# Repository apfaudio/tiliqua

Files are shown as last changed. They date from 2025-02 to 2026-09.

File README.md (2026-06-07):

# Tiliqua

**Tiliqua is a powerful, open hardware FPGA-based audio multitool for Eurorack.** It looks like this:



# ⮕[Documentation](https://apfaudio.github.io/tiliqua/)⬅

# Updates / Community

For updates, subscribe to the [Crowd Supply page](https://www.crowdsupply.com/apfaudio/tiliqua), join the [matrix chatroom](https://matrix.to/#/#apfaudio:matrix.org), or my own [mailing list](https://apf.audio/).

`apfaudio` has a Matrix channel, [#apfaudio:matrix.org](https://matrix.to/#/#apfaudio:matrix.org). Feel free to join to ask questions or discuss ongoing development.

Participants in this project are expected to adhere to the [Berlin Code of Conduct](https://berlincodeofconduct.org/).

# Contributing

For contribution guidelines and our policy on AI/LLM usage, see [CONTRIBUTING.md](CONTRIBUTING.md).

# Acknowledgements

This project would be nothing without the hard work of many (awesome) open-source projects. An exhaustive list would take pages, here I mention only a crucial subset:

- Python-based HDL and SoC framework: The [Amaranth HDL](https://github.com/amaranth-lang/amaranth) and [Amaranth SoC](https://github.com/amaranth-lang/amaranth-soc) projects.
- USB and SoC gateware: The [LUNA and Cynthion](https://github.com/greatscottgadgets/luna/) projects.
- RISCV softcore: The [VexRiscv and SpinalHDL projects](https://github.com/SpinalHDL/VexRiscv)
- USB audio gateware and descriptors: The [adat-usb2-audio-interface](https://github.com/hansfbaier/adat-usb2-audio-interface) project.
- Some gateware (e.g. I2C state machines) are inherited from the [Glasgow](https://github.com/GlasgowEmbedded/glasgow) project.
- Audio interface and gateware: my existing [eurorack-pmod](https://github.com/apfaudio/eurorack-pmod) project.
- SID emulation gateware: [reDIP-SID](https://github.com/daglem/reDIP-SID)
- The "mi-plaits-dsp-rs" project: [mi-plaits-dsp](https://github.com/sourcebox/mi-plaits-dsp-rs)
- The "pico-dirtyJtag" project forms a big chunk of the RP2040 firmware [pico-dirtyJtag](https://github.com/phdussud/pico-dirtyJtag)

## Funding

We would like to acknowledge partial funding of the [Tiliqua project](https://nlnet.nl/project/Tiliqua/) from the [NGI Commons Fund](https://nlnet.nl/commonsfund), a fund established by [NLnet](https://nlnet.nl/) with financial support from the European Commission’s [Next Generation Internet](https://ngi.eu/) program.



# License

The hardware and gateware in this project is largely covered under the CERN Open-Hardware License V2 CERN-OHL-S, mirrored in the LICENSE text in this repository. Some gateware and software is covered under the BSD 3-clause license - check the header of the individual source files for specifics.

**Copyright (C) 2024 Sebastian Holzapfel**

The above LICENSE and copyright notice do NOT apply to imported artifacts in this repository (i.e datasheets, third-party footprints), or dependencies released under a different (but compatible) open-source license.

# Derivative works

As an addendum to the above license: if you create or manufacture your own derivative hardware, the name `apf.audio`, the names of any `apf.audio` products and the names of the authors, are *not to be used in derivative hardware or marketing materials*, except where obligated for attribution and for retaining the above copyright notice.

For example, your 3U adaptation of "apf.audio Tiliqua" could be called "Gizzard Modular - Lizardbobulator".

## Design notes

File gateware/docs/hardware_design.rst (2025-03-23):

Electrical Design
#################

Tiliqua consists of 3 PCBAs. All of these are open-hardware designs built in KiCAD and stored in separate repositories.

Block Diagram (Tiliqua R4)
--------------------------

Below is high-level picture of how all the different electrical components of Tiliqua are connected.



Some connections are omitted for simplicity (example: some ex0/ex1 pins are connected to both the ECP5 and RP2040, not shown).

Pinouts and schematics
----------------------
- **Pinout information is available in 'amaranth-boards'** `format here <https://github.com/apfaudio/tiliqua/blob/main/gateware/src/tiliqua/tiliqua_platform.py>`_.
- **Schematics for all PCBAs in the wild are plotted** `to PDFs here <https://github.com/apfaudio/tiliqua/tree/main/hardware/schematics>`_.

We now follow with a summary of the core functions of each of the Tiliqua PCBAs.

Tiliqua Motherboard
-------------------

**Repository:** `tiliqua-motherboard <https://github.com/apfaudio/tiliqua/tree/main/hardware>`_

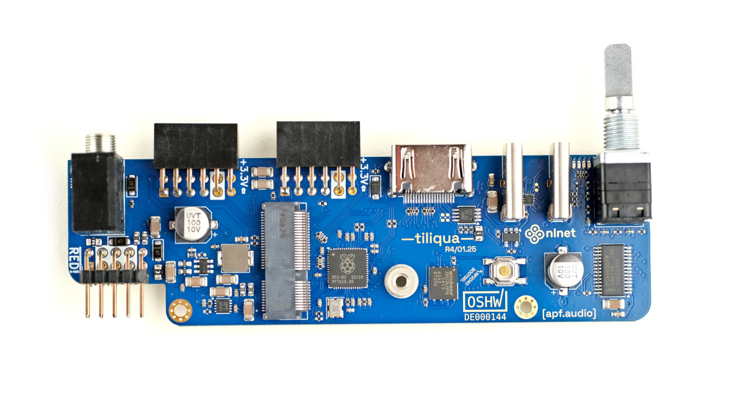
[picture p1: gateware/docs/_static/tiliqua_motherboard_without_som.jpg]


- Rotary encoder with button and bar graph display.
- RP2040-based JTAG debugger and UART bridge supported by `openFPGAloader`.
- Two USB ports:
    - `dbg`: USB FS for JTAG debugging.
    - `usb2`: 480Mbit/sec USB HS PHY connected to FPGA. Device, host and dual-role operation is supported on this port with a dedicated TUSB322I CC control IC and +5V VBUS switch.
- Display output for video synthesis
    - Maximum resolution 1280x720p/60Hz or 1920x1080p/30Hz.
- 2x (PMOD-compatible) expansion ports for up to 24 simultaneous audio channels.
- MIDI-In jack (TRS-A standard) with optoisolation.
- External PLL (SI5351A) for dynamic display resolution switching.
- Soft mute for pop-free bitstream switching

FPGA SoM (`soldiercrab`)
------------------------

**Repository:** `soldiercrab <https://github.com/apfaudio/soldiercrab>`_ (see README there for more detailed docs on this SoM)

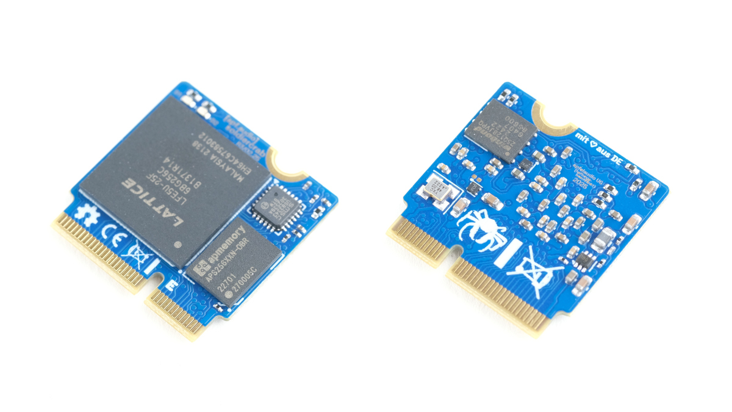
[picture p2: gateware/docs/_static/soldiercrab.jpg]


- Lattice ECP5 (25 K) FPGA, supported by open-source FPGA toolchains
- 256 Mbit (32 MByte) HyperRAM / oSPI RAM (for long audio buffers or video framebuffers)
- 128 Mbit (16 MByte) SPI flash for user bitstreams
- High-speed USB HS PHY (ULPI)

Audio Interface (`eurorack-pmod R3.3`)
--------------------------------------

**Repository:** `eurorack-pmod <https://github.com/apfaudio/eurorack-pmod/tree/master/hardware>`_

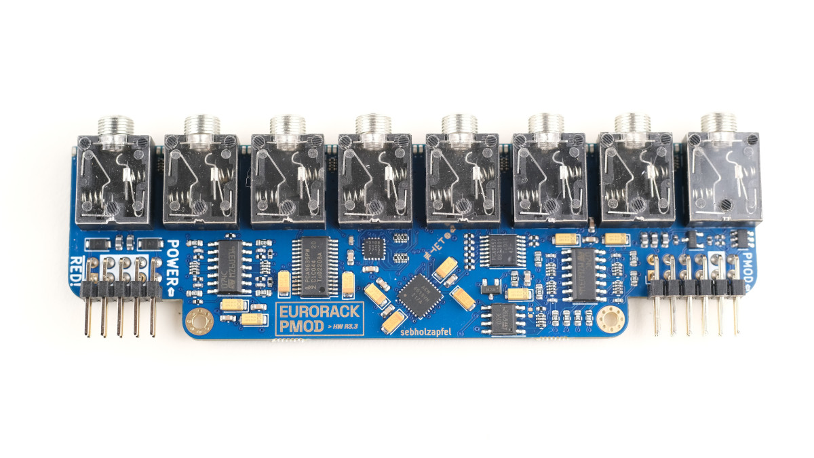
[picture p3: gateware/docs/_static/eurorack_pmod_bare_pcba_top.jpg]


- 8 (4 in + 4 out) DC-coupled audio channels, 192 KHz / 24-bit sampling
- Touch and proximity sensing on all 8 audio jacks (if unused)
- PWM-controlled, user-programmable red/green LEDs on each audio channel
- Jack insertion detection on all 8 jacks
- Built-in calibration EEPROM

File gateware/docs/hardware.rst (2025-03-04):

Connecting Hardware
###################

Connections: Front
------------------



Connections: Back
-----------------



Power: connecting +/- 12V
-------------------------

.. warning::

    Tiliqua uses an ordinary 10-pin power cable for +/- 12V ingress. You will notice however, that there are 2 such connectors on the module. **Only ONE of these should be connected**:

    - Use the 10-pin power ingress **on the Tiliqua Motherboard, not the Audio Interface Board**. Technically both will work, but only the former is fused.
    - Both connectors on the audio interface board (eurorack-pmod) should remain unconnected.
    - Make sure the red stripe on the IDC cable is aligned with the RED marker on the PCB.

USB: the ``dbg`` and ``usb2`` ports
-----------------------------------

For flashing bitstreams, you want the ``dbg`` USB port. This is routed to the on-board RP2040 which is flashed with ``dirtyJtag``, which allows flashing the SPI flash with ``openFPGALoader``.

For USB audio or USB device / host usage from bitstreams, you want the ``usb2`` USB port. This is routed through a ULPI PHY directly to the FPGA fabric.

Audio jacks: for touch, disconnect on boot
------------------------------------------

When using bitstreams with touch sensing, **ensure all jacks are disconnected before the tiliqua is powered on**. This is because the capacitive sensing is calibrated when the system boots. In the future, re-calibration will happen every time something is dis/re-connected, but this is not the case yet.

Display/DVI: disconnect when system off
---------------------------------------

External displays (e.g. external monitors not sharing Eurorack power) may leak a small current to the FPGA through the DVI termination resistors if Tiliqua is off. This will not affect Tiliqua operation, but may affect the 3V3 supply on PMOD expansion modules. By always **disconnecting the display when your eurorack system is off**, you can avoid this leakage current.

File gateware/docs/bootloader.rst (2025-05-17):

Bootloader
##########

User Interface
--------------

The bootloader allows you to arbitrarily select from one of 8 bitstreams after the Tiliqua powers on, without needing to connect a computer. In short:

- When Tiliqua boots, you can select a bitstream with the encoder (either using the display output, or by reading the currently lit LED if no display is connected).
- When you select a bitstream (press encoder), the bootloader bitstream:
    - Loads any required firmware to PSRAM and sets up any other settings requested in the bitstream manifest.
    - Commands the RP2040 over UART to issue a bitstream reconfiguration.
    - The RP2040 then commands the ECP5 (over JTAG) to reconfigure itself and enter the selected bitstream (loaded from the SPI flash local to the ECP5).
- From any bitstream, you can always go back to the bootloader by holding the encoder for 3sec (this is built into the logic of every bitstream).

Bitstream Archives and Flash Memory Layout
------------------------------------------

Tiliqua user projects are packaged into *Bitstream Archives*, which are ``.tar.gz`` files that contain everything the bootloader needs to start a custom bitstream. Each bitstream archive contains:

- Bitstream file (top.bit)
- Firmware binary (if applicable)
- Any extra resources to be loaded into PSRAM (if applicable)
- Manifest file (human-readable ``.json``) describing the contents

Tiliqua's ``pdm flash`` command manages the memory layout on the SoldierCrab's SPI flash, ensuring that the components of a bitstream archive end up in the correct place. A picture of how the SPI flash is organized:

.. code-block:: text

    ┌────────────────────────────┐  0x000000
    │                            │
    │    Bootloader Bitstream    │
    │                            │
    ├────────────────────────────┤
    │          (padding)         │
    ├────────────────────────────┤  0x0B0000
    │                            │
    │    Bootloader FW (XiP)     │
    │                            │
    ├────────────────────────────┤
    │          (padding)         │
    ╞════════════════════════════╡  0x100000
    │                            │
    │      Slot 0 Bitstream      │
    │                            │
    ├────────────────────────────┤
    │          (padding)         │
    ├────────────────────────────┤  0x1B0000
    │                            │
    │        Slot 0 FW           │
    │  NOT XiP, copied to PSRAM  │
    │                            │
    ├────────────────────────────┤  (any additional slot 0 resources appended here)
    │          (padding)         │
    ├────────────────────────────┤  0x1FFC00
    │      Slot 0 Manifest       │
    ╞════════════════════════════╡  0x200000 (End of Slot 0, start of Slot 1)
    │                            │
    │      Slot 1 Bitstream      │
    │                            │
    ├────────────────────────────┤
    │          (padding)         │
    ├────────────────────────────┤  0x2B0000
    │                            │
    │        Slot 1 FW           │
    │  NOT XiP, copied to PSRAM  │
    │                            │
    ├────────────────────────────┤ (any additional slot 1 resources appended here)
    │          (padding)         │
    ├────────────────────────────┤  0x2FFC00
    │       Slot 1 Manifest      │
    ╞════════════════════════════╡  0x300000 (End of Slot 1, start of Slot 2)
    │                            │

    ... continued up to Slot 7

- Bootloader bitstream: 0x000000
- User bitstream slots: 0x100000, 0x200000, etc (1MB spacing)
- Manifest: End of each slot (slot 0: 0x100000 + 0x100000 - 1024 (manifest size))
- Firmware: Loaded into PSRAM by bootloader, usually fixed offset from the bitstream start (i.e firmware for slot 0 is loaded from 0x100000 + 0xB0000 = 0x1B0000)

The manifest includes metadata like the bitstream name and version, as well as information about where firmware should be loaded in PSRAM.

If an image requires firmware loaded to PSRAM, the SPI flash source address (in the manifest) is set to the true firmware base address by the flash tool when it is flashed.
That is, the value of ``spiflash_src`` is not preserved by the flash tool and instead depends on the slot number.
This allows a bitstream that requires firmware to be loaded to PSRAM to be flashed to any slot, and the bootloader will load the firmware from the correct address.

Flashing the RP2040 and bootloader bitstream
--------------------------------------------

During normal use, it should not be necessary to flash the RP2040 or bootloader bitstream. However the instructions here may be useful for unbricking a device if you accidentally erased the bootloader, or want to update the bootloader on older hardware revisions. The bootloader is composed of 2 components that work together:

- The RP2040 firmware (`apfbug - fork of dirtyJTAG <https://github.com/apfaudio/apfbug>`_)
- The `bootloader <https://github.com/apfaudio/tiliqua/tree/main/gateware/src/top/bootloader>`_ top-level bitstream.

Flashing Steps
^^^^^^^^^^^^^^

1. Flash the RP2040. Use the latest pre-built binaries `found here <https://github.com/apfaudio/apfbug/releases>`_. To flash them, hold RP2040 BOOTSEL (golden button on the Tiliqua motherboard) before applying power, then copy the :code:`build/*.uf2` to the usb storage device and power cycle Tiliqua again. If you don't want to remove Tiliqua from your rack, you can also enter the RP2040 bootloader by opening a serial port at 1200 baud.

2. Build and flash the bootloader bitstream using the built-in flash tool (alternatively just download the latest bootloader archive from the CI artifacts):

.. code-block:: bash

    # Flash bootloader to start of flash, build assuming XIP (execute directly from SPI flash, not PSRAM)
    # Be careful to replace `--hw r4` with your hardware revision!
    pdm bootloader build --hw r4 --fw-location=spiflash
    pdm flash archive build/bootloader-r4/bootloader-*.tar.gz

3. Build and flash any other bitstreams you want to slots 0..7 (you can also download these archives from CI artifacts):

.. code-block:: bash

   # assuming the archive has already been built / downloaded
   pdm flash archive build/xbeam-r4/xbeam-*.tar.gz --slot 2

2. Check what is currently flashed in each slot (by reading out the flash manifests):

.. code-block:: bash

   pdm flash status

3. Before using the new bitstreams, disconnect the USB port and power cycle Tiliqua. (note: for the latest RP2040 firmware, this is not necessary and you can use them straight away).

.. warning::

    Before ``apfbug`` beta2 firmware, the bootloader would NOT reboot correctly (just show a blank screen) if you have
    the :py:`dbg` USB port connected WITHOUT a tty open. You HAD to have the
    ``/dev/ttyACM0`` open OR have the ``dbg`` USB port disconnected for it to work correctly.
    `Tracking issue (linked) <https://github.com/apfaudio/apfbug/issues/2>`_ (resolved in beta2 FW).

4. Now when Tiliqua boots you will enter the bootloader. Use the encoder to select an image. Hold the encoder for >3sec in any image to go back to the bootloader.

Technical Details
-----------------

Bootloader bitstream: ECP5
^^^^^^^^^^^^^^^^^^^^^^^^^^

The ECP5 :code:`bootloader` bitstream copies firmware from SPI flash to PSRAM before jumping to user bitstreams by asking the RP2040 to execute a stub bitstream replay (load a special bitstream to SRAM that jumps to the new bitstream). The request is issued over UART from the ECP5 to the RP2040, so it is visible if you have the ``/dev/ttyACMX`` open. User bitstreams are responsible for asserting PROGRAMN when the encoder is held to reconfigure back to the bootloader.

`apfbug` debugger firmware: RP2040
^^^^^^^^^^^^^^^^^^^^^^^^^^^^^^^^^^

:code:`apfbug` firmware includes the same features as :code:`pico-dirtyjtag` (USB-JTAG and USB-UART bridge), with some additions:

- UART traffic is inspected to look for keywords.
- If a keyword is encountered e.g. :code:`BITSTREAM1`, a pre-recorded JTAG stream stored on the RP2040's SPI flash is decompressed and replayed. The JTAG streams are instances of the `bootstub <https://github.com/apfaudio/tiliqua/blob/main/gateware/src/top/bootstub/top.py>`_ top-level bitstream. These are tiny bitstreams that are programmed directly into SRAM with the target :code:`bootaddr` and PROGRAMN assertion.
- This facilitates ECP5 multiboot (jumping to arbitrary bitstreams) without needing to write to the ECP5's SPI flash and exhausting write cycles.

Recording new JTAG streams for RP2040
^^^^^^^^^^^^^^^^^^^^^^^^^^^^^^^^^^^^^

TODO documentation on recording new JTAG bitstreams for storage on RP2040 flash - not necessary to change this for ordinary Tiliqua usecases. Note: SoldierCrab R3 and R2 use different ECP5 variants, so they need different RP2040 images. This is addressed by the ``TILIQUA_HW_VERSION_MAJOR`` cmake flag in the ``apfbug`` project.

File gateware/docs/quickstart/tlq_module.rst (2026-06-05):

Tiliqua Module [``TLQ-MODULE``]
###############################

**Tiliqua is shipped with a bunch of example bitstreams already flashed to it. So, to get started, all you need to do is connect the Eurorack +/- 12V ribbon cable, connect a screen, and then switch the Eurorack power on.**

.. warning::

    I recommend **only plugging or unplugging the display, power, or expansion headers while your system is OFF**. All other TRS jacks / USB connectors are fine to hotplug!



Connecting Power
^^^^^^^^^^^^^^^^

To power Tiliqua, you only need to connect the 16-pin Eurorack power input (+/- 12V) which, out of the box, is already attached to Tiliqua in the correct orientation.

.. note::

    Tiliqua comes with a rainbow power cable rather than a boring gray one. The connector is keyed correctly and the BROWN wire is the -12V wire. RED is still closest to -12V like on a standard gray one. Nothing bad will happen if you accidentally connect it backwards (on the 10-pin side), as Tiliqua has input diodes and fuses.

Connecting a Display
^^^^^^^^^^^^^^^^^^^^

Any standard monitor or projector (or our ``TLQ-SCREEN`` module) should work fine as a display for Tiliqua. In general, Tiliqua tries to use the native resolution of any attached screen. However, if the native resolution is higher than ``1280x720p60``, or no screen is connected at all, we always emit a display signal at ``1280x720p60`` as a fallback - as the vast majority of screens support this resolution.

Bootloader
^^^^^^^^^^

After powering on your system, you will be greeted by the bootloader screen:



From here, you can use the encoder to select one of 8 slots. As each slot is highlighted, the I/O mapping of each jack and plug is pictured on the right. You will notice some bitstreams have USB, some don't, some have a display output and others don't (like the audio-only bitstreams).

To reboot into a selected bitstream, just press the encoder button. **Once you're in a bitstream, you can always hold the encoder button down for 3sec (long press) to mute Tiliqua and re-enter the bootloader.**

.. note::

   At the moment, the screen resolution and/or any screen hotplugs are only detected in the bootloader. This is not a hardware limitation, but it does mean that for now you always need to be in the bootloader to change screen resolutions. The current resolution is displayed at the bottom of the bootloader screen.

   In general, bitstreams will show ``video: <match-bootloader>`` if they are able to inherit the resolution automatically detected by the bootloader. If a bitstream only supports a static mode, you will see something like ``video: 1280x720p60``. If a bitstream does not have any video output, you will see ``video: <none>``.

Menu / Help system
^^^^^^^^^^^^^^^^^^

In theory, each user bitstream could have a completely different UI. For now though, most bitstreams that have a display output and are shipped with Tiliqua follow the same menu UI. That is:

    - Each bitstream has multiple 'pages', where the first page is a 'HELP' page.
    - Rotating the encoder allows you to select a different menu option or the current page name.
    - If the current page name is selected, pressing the encoder will toggle between modifying the current page or not, rotating it will switch to a different page.
    - If normal option is selected, pressing the encoder will toggle between modifying the value or not, rotating it will increase or decrease the value.
    - In this way, you can access one of many pages and modify one of many options on each page with the single encoder.
    - If no option is selected for modification and we are not on the help page, the UI will disappear after some time (useful for generating visualizations).



    HELP page for XBEAM user bitstream.

Using Bitstreams
^^^^^^^^^^^^^^^^

.. note::

    The instructions here are always for the **latest firmware** - if the version shown at the bottom of the screen for any bitstream is not up-to-date (matching the latest `version number / changelist here <https://github.com/apfaudio/tiliqua/releases>`_), I recommend updating! (instructions below)

Out of the box, Tiliqua ships with the following example bitstreams flashed. Many of them have built-in help pages. Here is a link to some more info on each one:

- :ref:`XBEAM <xbeam>`
- :ref:`POLYSYN <polysyn>`
- :ref:`MACRO-OSC <macro_osc>`
- :ref:`SID <sid>`
- :doc:`SELFTEST <../calibration>`
- :ref:`SAMPLER <sampler>`
- :class:`DSP-MDIFF <top.dsp.top.PSRAMMultiDiffuser>`
- `VSYNTH <https://github.com/apfaudio/tiliqua/issues/160>`_ (preview!)

.. warning::

    The documentation for each bitstream is not quite polished yet, but I hope there is enough material for you to be able to get started with the most important ones.

Jack LEDs
^^^^^^^^^

Normally, the Jack LEDs on each audio jack show the current voltage on the jack. However, whenever you are modifying an option or touching the encoder, the jack LEDs take on a different meaning.

This is because, in cases where you want to use a bitstream that has a menu system but **don't have space for a display** (and are extremely dedicated and memorised the menu) it is possible to navigate purely based on the jack LEDs!

    - If jack LED is green: we are selecting a page. The jack LED number (0-7) is the page number.
    - If jack LED is red: we are selecting an option. The jack LED number (0-7) is the option index.
    - If the jack LED is flashing: we are in 'modify' mode. If it is not flashing, we are NOT in 'modify' mode.
    - The bar graph LEDs around the encoder show the currently selected option's value on a scale from min (fully green) to max (fully red).

Touch Sensors
^^^^^^^^^^^^^

The capacitive touch sensors on each jack are calibrated when Tiliqua is turned on, and in some bitstreams (like POLYSYN), automatically re-calibrated every time a jack is plugged or unplugged. If you are having issues with 'ghost' touches, it's often worth power cycling tiliqua with nothing patched on the jacks you want to use for touch sensing.

USB: the ``dbg`` and ``usb2`` ports
-----------------------------------

For flashing bitstreams, you want the ``dbg`` USB port. This is routed to the on-board RP2040. For USB audio or USB device / host usage from bitstreams, you want the ``usb2`` USB port. This is routed through a ULPI PHY directly to the FPGA fabric.

.. note::

   **If you are having trouble with the ``usb2`` port for USB audio streaming or as a MIDI host**, I have collected some :doc:`USB troubleshooting tips here <../usb_troubleshooting>`.

Flashing/Updating Bitstreams
^^^^^^^^^^^^^^^^^^^^^^^^^^^^

Tiliqua can be updated / flashed in 2 ways:

- Use the **tiliqua-webflash** `(LINK) <https://apfaudio.github.io/tiliqua-webflash/>`_ tool, which works in any Chromium-based browser and allows you to flash bitstream archives to Tiliqua using any OS.
- Using our ``pdm flash`` **command line tool**, which requires setting up the Tiliqua development environment first. More details in :doc:`../install`.

With **tiliqua-webflash**, the latest release is always shown - no need to download anything. For command line, you can find the latest `published release here <https://github.com/apfaudio/tiliqua/releases>`_.

Tiliqua has 9 slots (bootloader + 8 user slots). Generally, you want to keep all of these up-to-date, however, as they are independent, you can have different versions of things in every slot. You'll find instructions on how to update each slot in the respective flashing tool.

.. note::

    **Technical details for the curious!** Tiliqua has 3 persistent memory chips that come pre-flashed out of the box. **Flashing / updating bitstreams only touches the first one.**

        - On the 'Soldiercrab': one 16MB SPI flash for the FPGA: This one contains the bootloader bitstream and all the user bitstreams, and any saved options.
        - On the 'Motherboard':  16MB SPI flash for the RP2040 / debugger: this one contains the debugger firmware used as a bridge between the ``dbg`` USB port and the FPGA JTAG.
        - On the 'Audio Board': one small EEPROM for storing calibration constants, as well as the last entered bitstream used for autoboot. This contains the factory calibration.

    **Under the hood**: updating or changing the bootloader bitstream or user bitstreams is performed using an open-source tool called ``openFPGALoader``, as Tiliqua shows up as a ``dirtyJtag``-compatible debug adapter. Bitstreams for Tiliqua are distributed as *Bitstream Archives*, which contain firmware and metadata alongside the bitstream itself. For technical details on how this works, see :doc:`../bootloader`).

Calibration
^^^^^^^^^^^

Tiliqua is shipped with a factory calibration to within 5mV or so. If you want to get even better, you can try to calibrate it yourself by following the calibration sequence here: :doc:`../calibration`

.. warning::

    Before you conclude the NCO V/oct calibration is bad, note the calibration currently is only applied in bitstreams that have a menu system as reading the calibration uses a CPU. This limitation will be removed in a future update.

Hardware Block Diagram
^^^^^^^^^^^^^^^^^^^^^^

For deeper details (and schematics) of the hardware, see :doc:`../hardware_design`



Instructions for Safe Use
^^^^^^^^^^^^^^^^^^^^^^^^^

- The product shall only be used in a Eurorack system, providing a standard Eurorack power supply not exceeding +/- 12V, and at least 500mA. Any external case, power supply, cables, or modules shall comply with relevant regulations and standards applicable in the country of intended use.
- To reach electromagnetic compatibility in a Eurorack system, the product shall be mounted securely in a fully enclosed housing made of conductive material (metal). Close all unused spaces with blind panels. Keep all cables, power or patch cables as short as possible.
- The product should only be operated in a well ventilated case and should not be covered, except by the Eurorack case itself or other module panels. The product is designed for reliable operation at normal ambient room temperature. Do not expose the module to water, moisture or bring the circuit boards in contact with any conductive materials.
- Take care whilst handling to avoid mechanical or electrical damage. When the product is powered on, do not touch any of the circuit boards behind the front panel. When the product is outside a case, only handle it unpowered and by the edges to minimize the risk of damage from electrostatic discharge.
- Do not supply power to the product through any receptacle except the main +/- 12V power input. Any external devices not sharing the product’s main power bus (e.g. USB host devices or externally powered displays) should be disconnected when the product is unpowered. The incorrect usage or connection of unapproved devices to any receptacle may affect compliance or result in damage to the unit and invalidate the warranty.
- Use of any firmware, gateware or clock frequencies not explicitly provided by the manufacturer is to be done at your own risk, in a controlled laboratory environment, with respect to relevant regulations and standards applicable in the country of intended use.

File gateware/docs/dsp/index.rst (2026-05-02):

DSP Library
###########

Philosophy
----------

Tiliqua's DSP library is designed as a suite of DSP components - independent 'cores' which can be connected together in different ways in order to build a custom DSP pipeline. It makes heavy use of Amaranth streams (`lib.stream <https://amaranth-lang.org/docs/amaranth/latest/stdlib/stream.html>`_) for connecting components and `lib.fixed <https://github.com/amaranth-lang/amaranth/pull/1578>`_ for fixed-point types. `lib.stream <https://amaranth-lang.org/docs/amaranth/latest/stdlib/stream.html>`_ makes it possible to chain DSP components together in different ways (without components needing to know implementation details of each other), and `lib.fixed <https://github.com/amaranth-lang/amaranth/pull/1578>`_ makes it easier to write common numeric operations in Amaranth.

.. note::

    Streams are an Amaranth construct describing a *stream of data* that is accompanied by a ``valid``/``ready`` handshake. This is a simple protocol used commonly in digital logic. For more details, see `Data streams <https://amaranth-lang.org/docs/amaranth/latest/stdlib/stream.html>`_ in the Amaranth documentation.

Interconnect
------------

Building a custom DSP pipeline with the components provided here is often an act of figuring out how to massage the input and output ports of each component such that the design does what you want. In simple cases, like oscillators or filters, DSP components will often have a ``self.i`` stream for incoming and ``self.o`` stream for outgoing samples - these can be chained together in any order using `wiring.connect() <https://amaranth-lang.org/docs/amaranth/latest/stdlib/wiring.html>`_. In more complex cases, like delay lines, components may expose a memory bus (for writes to external memory), multiple input or output ports, or global registers. It is important to read the documentation of each component and take a look at some of the example cores in order to understand how each component can be used, and how exactly input and output samples are synchronized.

As of now, input and output ports of DSP components generally take on one of the following shapes:

    - ``stream.Signature(fixed.SQ)``: A stream of audio samples, one at a time.
    - ``stream.Signature(ArrayLayout(N, fixed.SQ))``: A stream of N audio samples, one 1D array at a time. This is used for multi-channel, time-synchronized inputs and outputs -- like Tiliqua's 4 inputs or 4 outputs, or the :class:`tiliqua.dsp.MatrixMix` component. These can be split into streams of single samples using :class:`tiliqua.dsp.Split` or :class:`tiliqua.dsp.Merge` (see :doc:`stream_util`).
    - ``stream.Signature(StructLayout({...}))``: A stream of N different types of data, one set at a time. This is often used when each audio sample needs a piece of metadata alongside it (e.g. realtime tweakable filters like :class:`tiliqua.dsp.SVF`).
    - ``stream.Signature(Block(...))``: Some components can only operate on blocks of samples, like :class:`tiliqua.dsp.fft.FFT` - see :doc:`block` for details.

The art is in knowing exactly which components can be used in translating between the interface styles. For example, :class:`tiliqua.dsp.fft.ComputeOverlappingBlocks` can help going from a sample stream to a block stream. :class:`tiliqua.dsp.Split` for going from an `ArrayLayout <https://amaranth-lang.org/docs/amaranth/latest/stdlib/data.html#amaranth.lib.data.ArrayLayout>`_ to independent sample streams. Depending on the application, often `StructLayout <https://amaranth-lang.org/docs/amaranth/latest/stdlib/data.html#amaranth.lib.data.StructLayout>`_ streams will need some manual handshaking logic. There is no one right answer for every adaptation, especially in cases where you have some control signals alongside synchronized audio streams.

A few components have auxiliary interfaces to the outside world. Examples are :class:`tiliqua.dsp.DelayLine`, which may have a ``bus`` port to talk to external memory (for storing audio samples), or ``usb_audio`` components which require a connection to a USB PHY to service their audio in/out streams.

'Basic' and 'Specialized' components
------------------------------------

DSP cores are split into 2 types, 'Basic' and 'Specialized'. Basic cores do not require qualified access - after a statement like ``from tiliqua import dsp``, these can be accessed through :class:`dsp.Split <tiliqua.dsp.Split>` or similar. 'Specialized' cores need qualified access and may be accessed through :class:`dsp.fft.STFTProcessor <tiliqua.dsp.fft.STFTProcessor>` or similar.

Basic DSP Components
--------------------

.. toctree::
   :maxdepth: 2

   delay_lines
   filters
   oscillators
   effects
   vca
   mix
   resample
   oneshot
   stream_util
   misc

Specialized Modules
-------------------

.. toctree::
   :maxdepth: 2

   delay_effect
   fft
   spectral
   mac
   block
   complex
   cordic

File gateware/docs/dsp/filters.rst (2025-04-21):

Filters
-------

.. autoclass:: tiliqua.dsp.SVF
.. autoclass:: tiliqua.dsp.FIR
.. autoclass:: tiliqua.delay.Boxcar

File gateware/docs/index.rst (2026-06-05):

Tiliqua Project
###############

The **Tiliqua Project** aims to make FPGA-based audio and video synthesis more accessible.



    TLQ-MODULE and (optional) matching TLQ-SCREEN patched in a Eurorack System

Tiliqua is a **Eurorack Module**, which contains a debugger, FPGA and high-fidelity DC-coupled audio IOs, amongst lots of other features. It can store multiple bitstreams, and has a bootloader to select between them - making the hardware fully reconfigurable during live performance.

.. note::

    **If you just received Tiliqua hardware -- Quickstart is where you should begin!**

.. toctree::
   :caption: Quickstart
   :maxdepth: 2

   quickstart/tlq_module.rst
   quickstart/tlq_screen.rst
   quickstart/tlq_expander.rst
   quickstart/tlq_soldiercrab.rst

.. toctree::
   :caption: Development Guide
   :maxdepth: 3

   install
   building_flashing
   audio_bitstreams
   custom_dsp
   beamrace_video
   cpu_bitstreams
   bootloader

.. toctree::
   :caption: Reference
   :maxdepth: 3

   examples/index
   dsp/index
   calibration
   usb_troubleshooting

.. toctree::
   :caption: Hardware Details
   :maxdepth: 2

   hardware_design
   hardware_changes

.. toctree::
   :caption: Keep Updated
   :maxdepth: 2

   community
   foss_funding
   devlog/index

.. toctree::
   :caption: Links
   :maxdepth: 2

   Tiliqua Webflasher <https://apfaudio.github.io/tiliqua-webflash/>
   Tiliqua on Crowd Supply <https://www.crowdsupply.com/apfaudio/tiliqua>
   Tiliqua on GitHub <https://github.com/apfaudio/tiliqua>
   Homepage (apf.audio) <https://apf.audio/>

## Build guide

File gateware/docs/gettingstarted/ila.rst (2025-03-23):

Using the ILA
=============

Some cores support using a built-in ILA (integrated logic analyzer), to collect waveform traces on the hardware into on-FPGA block RAM, which is sampled at the system clock and dumped out the serial port.

For example:

.. code-block:: bash

   # from `gateware` directory
   pdm vectorscope_no_soc build --ila --ila-port /dev/ttyACM0

This will build the bitstream containing the ILA, flash the bitstream, then open the provided serial port waiting for an ILA dump from the Tiliqua to arrive. Once received, the dump will be saved to a waveform trace file.

.. note::
   You may have to play with permissions for flashing to work correctly - make sure ``openFPGALoader`` can run locally under your user without ``sudo``.

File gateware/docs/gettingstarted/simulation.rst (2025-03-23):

Simulating designs
==================

Simulating DSP cores
--------------------

The easiest way to debug the internals of a DSP project is to simulate it. This project provides some shortcuts to enable simulating designs end-to-end with Verilator (at some point these will be migrated to Amaranths CXXRTL simulation backend, once it lands).

For example, to simulate the waveshaping oscillator example:

.. code-block:: bash

   # from `gateware` directory
   pdm dsp sim --dsp-core nco

In short this command:

- Elaborates your Amaranth HDL and convert it to Verilog
- Verilates your verilog into a C++ implementation, compiling it against ``sim_dsp_core.cpp`` provided in ``gateware/top/dsp`` that excites the audio inputs (you can modify this).
- Runs the verilated binary itself and spits out a trace you can view with ``gtkwave`` to see exactly what every net in the whole design is doing.

Simulating SoC cores
--------------------

A subset of SoC-based top-level projects also support end-to-end simulation (i.e including firmware co-simulation). For example, for the selftest SoC:

.. code-block:: bash

   # from `gateware` directory
   pdm selftest sim

   # ...

   run verilated binary 'build/obj_dir/Vtiliqua_soc'...
   sync domain is: 60000 KHz (16 ns/cycle)
   pixel clock is: 74250 KHz (13 ns/cycle)
   [INFO] Hello from Tiliqua selftest!
   [INFO] PSRAM memtest (this will be slow if video is also active)...
   [INFO] write speed 1687 KByte/seout frame00.bmp
   c
   [INFO] read speed 1885 KByte/sec
   [INFO] PASS: PSRAM memtest

UART traffic from the firmware is printed to the terminal, and each video frame is emitted as a bitmap. This kind of simulation is useful for debugging the integration of top-level SoC components.

Simulating vectorscope core
---------------------------

There is a top-level ``vectorscope_no_soc`` provided which is also useful for debugging integration issues between the video and memory controller cores. This can be simulated end-to-end as follows (``--trace-fst`` is also useful for saving waveform traces):

.. code-block:: bash

   # from `gateware` directory
   pdm vectorscope_no_soc sim --trace-fst

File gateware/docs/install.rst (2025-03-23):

Prerequisites
#############

On an Ubuntu system, the following are the main dependencies:

- The build system: install `pdm <https://github.com/pdm-project/pdm>`_
- For synthesis/simulation: install `oss-cad-suite <https://github.com/YosysHQ/oss-cad-suite-build>`_ (and see note below)
- For any SoC examples that include a CPU: `rust <https://rustup.rs/>`_

  - To build stripped images for RISC-V, you also need:

    .. code-block:: bash

       rustup target add riscv32im-unknown-none-elf
       rustup target add riscv32imafc-unknown-none-elf # for `macro_osc` only, it uses an FPU
       rustup component add rustfmt clippy llvm-tools
       cargo install cargo-binutils svd2rust form

.. note::
    By default, synthesis will use :code:`yowasp-yosys` and :code:`yowasp-nextpnr-ecp5` (python packages), rather than any :code:`oss-cad-suite` you have installed. When running locally, builds are usually faster if you point to your own installation - modify :code:`gateware/.env.toolchain` (simply deleting it will try to find yosys in your PATH).

To set up the repository:

.. code-block:: bash

   cd gateware
   git submodule update --init --recursive

To install all python dependencies in a PDM-managed venv:

.. code-block:: bash

   pdm install

.. note::

    Most examples are built in CI. If you're having trouble setting up your environment, it may also be worth checking the github workflow configuration.

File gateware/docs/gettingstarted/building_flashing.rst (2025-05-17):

Building and flashing examples
==============================

Building
--------

Each top-level bitstream has a command-line interface. You can see the options by running (for example):

.. code-block:: bash

   # from `gateware` directory
   pdm dsp

The available options change depending on the top-level project. For example, many projects have video output, and from the CLI you can select the video modeline.

.. warning::

    For prototype Tiliqua hardware, be careful to add an :py:`--hw r4` (or similar) flag specifying your hardware version to all commands below.

A few examples of building top-level bitstreams:

.. code-block:: bash

   # from `gateware` directory

   # for the selftest bitstream (prints diagnostics out DVI and serial)
   pdm selftest build
   # for a vectorscope / oscilloscope
   pdm xbeam build
   # for a polyphonic MIDI synth
   pdm polysyn build
   # for the LUNA-based 4in + 4out USB soundcard example
   # note: LUNA USB port presents itself on the second USB port (not dbg)!
   pdm usb_audio build
   # for a 4-channel waveshaping oscillator
   pdm dsp build --dsp-core nco
   # for a diffusion delay effect
   pdm dsp build --dsp-core diffuser
   # simplified vectorscope (no SoC / menu system)
   pdm vectorscope_no_soc build

Generally, bitstreams are also built in CI - check ``.github/workflows`` if you need more gruesome details on how systems are built.

For SoC projects that have firmware, for quicker iteration, ``--fw-only`` is useful to only re-build the firmware for that bitstream and repackage the archive, without re-synthesizing the bitstream (which often takes quite a while).

Flashing
--------

When you build projects from the command line, it will create a *Bitstream Archive*, which is a ``.tar.gz`` file that contains everything the bootloader needs to start a custom bitstream. Details on the inner workings of these archives can be found in the :doc:`../bootloader` section.

You can flash custom bitstreams to one of 8 slots, using the built-in ``pdm flash`` command. To flash a bitstream archive you have just built, you can use ``pdm flash archive`` as follows:

.. warning::

    For prototype hardware, you may need to reflash the RP2040 and bootloader bitstream  per :doc:`../bootloader`, before the following instructions will work.

.. code-block:: bash

   # Flash user bitstreams to the desired slot (0-7)
   pdm flash archive build/selftest-r4/selftest-*.tar.gz --slot 1
   pdm flash archive build/xbeam-r4/xbeam-*.tar.gz --slot 2

``pdm flash`` also supplies a ``status`` command to read back the Tiliqua's SPI flash to see what is currently on there:

.. code-block:: bash

   pdm flash status

.. note::

    If you want to avoid audio pops while flashing, it is best to flash from the bootloader bitstream, as the audio CODEC is always muted in that bitstream.

If you are running an SoC, you can monitor serial output like so:

.. code-block:: bash

   sudo picocom -b 115200 /dev/ttyACM0

For non-SoC projects that don't require extra firmware, note that you can also directly flash bitstreams to the SRAM of the FPGA like so:

.. code-block:: bash

   sudo openFPGALoader -c dirtyJtag build/dsp-mirror-r4/top.bit

This flashes much quicker, as we don't have to wait for flash pages to update. This can be useful for quickly iterating on DSP gateware. In the future, this will be possible with SoC bitstreams as well, but requires an extra bridge to directly stream debug firmware to the PSRAM from the host, which isn't implemented yet.

Video Modes
-----------

From the Tiliqua bootloader (or whenever a display is hotplugged whilst in the bootloader), Tiliqua reads the attached display EDID to determine which display timings to use. Tiliqua will adapt to the first timing descriptor it finds, and if none of them can be met (usually if the pixel clock is too fast), it falls back to 1280x720p60. You can inspect the logs as to how the bootloader decided which display mode to use by looking at the serial telemetry on the debug port.

Depending on the project, Tiliqua user bitstreams may:

- Not use the video output at all (for example ``pdm dsp`` and ``pdm usb_audio`` are audio-only)
- Use a static video mode (for example ``pdm vectorscope_no_soc``)
- Support dynamic video modes (all SoC bitstreams)

Dynamic video modes are useful as the same bitstream can be used/shared, regardless of which screen is plugged in. When dynamic video modes are supported, the user bitstream will inherit the video mode that was autodetected by the bootloader (this is communicated by a ``bootinfo`` struct saved to PSRAM before the user bitstream is booted).

.. note::

   If for some reason you want to disable EDID reading and use a static/specific mode, you can always re-build and re-flash all bitstreams using a flag like ``--modeline 1280x720p60`` to force a static modeline, disabling dynamic mode detection. Note that the bootloader built with a static modeline can *only* start bitstreams that are also built with a static modeline, however a bootloader built for dynamic modelines can start *both* types of bitstreams. The bootloader will display an error if these conditions are not met.

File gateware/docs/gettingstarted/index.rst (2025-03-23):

Getting Started
###############

.. toctree::
   building_flashing
   simulation
   ila

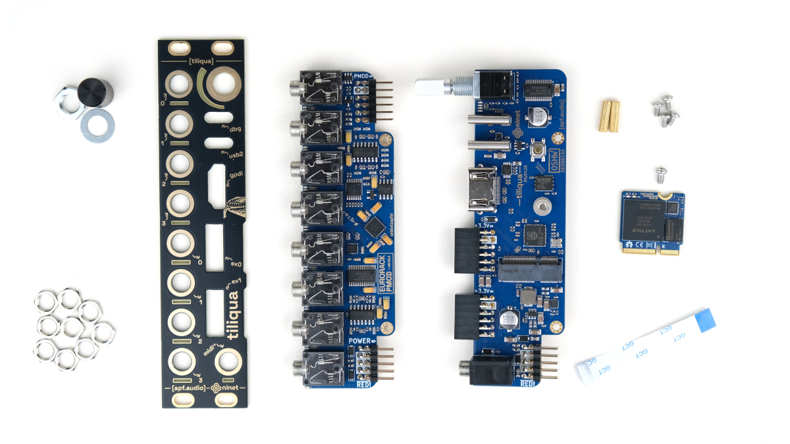
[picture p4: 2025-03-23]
gateware/docs/_static/tiliqua_disassembled_top.jpg

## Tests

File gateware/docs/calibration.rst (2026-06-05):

Calibration
###########

Background
----------

To support eurorack-level control voltages (CV), all inputs and outputs are DC-coupled. Audio codecs (such as the AK4619VN used here) are usually not designed for DC-coupled operation, which means that they often have quite large DC zero offsets and scaling terms compared to instrumentation converters.

.. note::

    Without any calibration at all, the inputs and outputs will should have an error < 150mV or so across the range. Most examples will deal with this fine, however if you are driving or being driven by Eurorack V/oct tunings, 1 semitone is in the order 80mV. So, if you need to be pitch-perfect, calibration is worthwhile.

To reduce the tracking error, each input and output supports independent DC offset and scale correction factors:

- For input ADCs, ``i = A * I + B``, where ``i`` is the calibrated input, ``I`` is the raw ADC count and ``A``, ``B`` are correction factors.
- For output DACs, ``O = C * o + D``, where ``o`` is the desired output, ``C`` and ``D`` are correction factors, and ``O`` is the raw DAC count.

Note that internally, the correction algorithm for inputs and outputs is identical. At the moment, audio samples are 16-bit fixed-point (shorthand ``ASQ`` in the code) with a range from ``-1..1`` where (when calibrated) ``+1 == +8.192V`` (i.e 4 raw counts per mV). Both input and output sides can support wider voltage ranges, however this is currently what the codebase uses everywhere, and wide enough for most purposes.

All correction factors are stored as 18-bit fixed-point numbers with a range ``-4..4``. Usually the scaling correction factors are close to ``1``, and the zeroing correction factors are close to ``0``.

Calibrating the ADCs/DACs
-------------------------

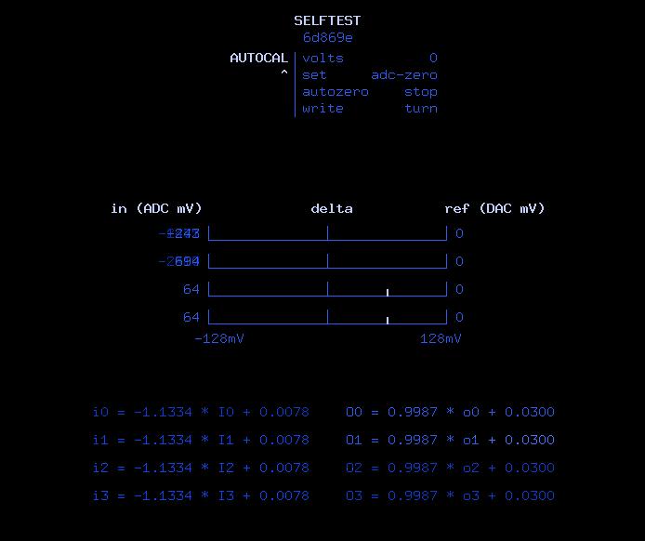
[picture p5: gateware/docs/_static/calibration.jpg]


Pictured above, the ``selftest`` bitstream provides a semi-automated way of performing ADC/DAC calibration.
In short, the process is as follows:

- Disconnect all jacks. Power up Tiliqua, select ``selftest`` bitstream, ensure startup report is healthy.
- Switch to the ``AUTOCAL`` screen. The display will show the following options:

    - ``volts``: DAC reference level. This determines the value sent to the DAC. It is also subtracted from the ADC readings to form the 'delta' plot pictured on the main screen.
    - ``set``: Calibration coefficient to be automatically adjusted. The utility will adjust the selected coefficients until the 'delta' plot on the main screen has been zeroed.
    - ``autozero``: Enable autozero. When set to ``off``, nothing is adjusted. When set to ``run``, the selected calibration coefficients will be adjusted. Usually, you switch to ``run`` until the values are zeroed, then switch it off again.
    - ``write``: Write constants to non-volatile EEPROM and print them out the serial port.

- **Step 1** ADC zero:

  - With all jacks disconnected, set ``volts=0``, ``set=adc-zero``.
  - Switch ``autozero=run`` until the 'delta' plots hit zero. Switch back to ``autozero=stop``
  - You will notice the calibration equations at the bottom of the screen updated during the zeroing process.

- **Step 2** ADC scale:

  - Set an external precise voltage source to the desired test voltage, for example 3V.
  - With the first jack connected to your voltage source, set ``volts=3``, ``set=adc-scale``.
  - Switch ``autozero=run`` until the 'delta' plots hit zero.
  - Plug in the voltage source to the other jacks in sequence until they all also hit zero. Alternatively, you can just plug all the jacks into one voltage source at the same time, that's up to you.
  - Switch back to ``autozero=stop``
  - Now the ADCs are calibrated, you can test the range by injecting different voltages and adjusting ``volts`` to move the reference.

- **Step 3** DAC zero:

  - Now that all the ADCs are calibrated, we can use the ADC calibration to calibrate the DACs.
  - Connect all outputs to inputs in loopback with 4 patch cables (i.e. output 0 to input 0, output 1 to input 1 and so on).
  - Set ``volts=0``, ``set=dac-zero``. You will see see the DAC output zero offsets, as the ADCs were already zeroed.
  - Switch ``autozero=run`` until the 'delta' plots hit zero. Switch back to ``autozero=stop``

- **Step 4** DAC scale:

  - Set ``volts=3``, ``set=dac-scale``. The ADC readings should already be pretty close to the target.
  - Switch ``autozero=run`` until the 'delta' plots hit zero. Switch back to ``autozero=stop``

- **Step 5** Save the results

  - Select ``write`` from the menu and turn the encoder to save the calibration to non-volatile EEPROM on the eurorack-pmod PCBA. The constants are also printed out the serial port. On switching to other bitstreams or returning to this bitstream, the previous calibration will be loaded from EEPROM.

.. note::

    As of now, the calibration constants are only loaded from EEPROM in bitstreams that have an SoC. If you want to use the calibration constants in a bitstream without a SoC, for now you can copy and paste the serial-port dump into the default calibration you will find in ``eurorack_pmod.py``.

- **You are done!** optionally, you can also tweak the cal constants from the ``TWEAK-ADC`` and ``TWEAK-DAC`` screens.

.. note::

    **On R4 (and earlier) Tiliqua hardware:** During calibration, you may notice the DC offsets moving around ~10mV depending on whether the LEDs are on or off. This is due to the CODEC voltage regulator. In any case, it's best to do the calibration assuming the LEDs are ON, as that is the state they will be in most of the time Tiliqua is being used.

    **On R5+ Tiliqua hardware:** Reproducible calibration at <5mV absolute accuracy should be easy to achieve, since I added an extra voltage regulator isolated to the CODEC.

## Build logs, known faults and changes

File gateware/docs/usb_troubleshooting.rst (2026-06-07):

USB troubleshooting
===================

This page collects some tips I have collected after helping a couple of users fight with Tiliqua's USB-C ports on different operating systems.

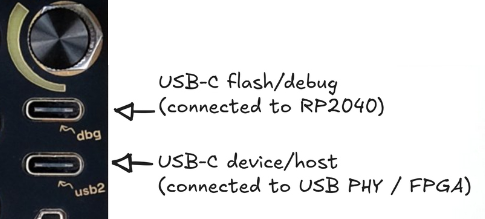
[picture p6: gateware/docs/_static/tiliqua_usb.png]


Tiliqua has 2 USB ports:

    - The top one ``dbg`` is for updating Tiliqua.
    - The bottom one ``usb2`` is for use by user applications. *This is used for example by XBEAM for USB audio streaming (in USB DEVICE mode), or by POLYSYN for USB MIDI (in USB HOST mode).*

``dbg`` USB port (top, for flashing)
^^^^^^^^^^^^^^^^^^^^^^^^^^^^^^^^^^^^

Webflasher doesn't work
-----------------------

Depending on your OS, you may need to do some setup before being able to flash your device with `tiliqua-webflash <https://apfaudio.github.io/tiliqua-webflash/>`_. These tips are at the bottom of the webflasher page, and copied here:

    - macOS: No setup needed.
        - Note: I had one report that the webflasher does not work with very old versions of OS X (i.e a few years old).
    - Windows: Use `Zadig <https://zadig.akeo.ie/>`_ to install a WinUSB driver for the device:
        - Plug in Tiliqua
        - Run Zadig
        - In the menu, under 'Options', choose 'List All Devices'
        - In the main drop down, select the Tiliqua 'apfbug' device
        - Select 'WinUSB' in the drop down near the green arrow
        - Click 'Install Driver', wait for it to complete.
        - Refresh this page, flashing should work.
    - Linux: You may need to add a `udev rule <https://apfaudio.github.io/tiliqua/install.html#check-usb-device-permissions>`_ so Tiliqua can be accessed without sudo.

``usb2`` USB port (bottom, audio/MIDI)
^^^^^^^^^^^^^^^^^^^^^^^^^^^^^^^^^^^^^^

USB audio - nothing enumerates
------------------------------

Assuming you are in an app with USB streaming (like XBEAM) -- if you are using a USB-C to USB-C cable and your OS does not show *anything at all* when plugged into the ``usb2`` port :
    - Try a different USB-C cable. The nice 5GBps+ ones are more likely to be good.
    - If this doesn't work, try using a USB-A to USB-C cable instead.

USB audio - glitchy audio (any OS)
----------------------------------

Assuming you are in an app with USB streaming (like XBEAM) -- if you hear periodic popping, this usually due to:
    - **`usb-mode` setting:** For USB audio streaming, I recommend always setting ``MISC->usb-mode=enable`` BEFORE plugging in your PC. Otherwise, the USB audio clock sync can get confused in rare cases.
    - **USB cable:** if you are using a long USB cable - especially longer than 2m or so, this can cause USB packet loss. Try the same cable with a normal USB audio interface, you'll usually get pops there as well if the cable is too long.
    - **Buffer size:** It depends which driver and OS you are using, what is optimal, but I recommend playing with buffer sizes between 128 and 2048 to see what works best on your machine.

USB audio - Windows / WASAPI shows separate input and output devices
--------------------------------------------------------------------

Some versions of Windows cause WASAPI to enumerate Tiliqua's 4 IN and 4 OUT channels as separate devices. There are 2 ways you can deal with this:
    - **Instantiate both devices** - In VCVRack you can just create 2 separate modules for the input and output sides, and use them together. This has the downside that you may need high buffer sizes like 1024 for it to work glitch-free.
    - **Try switching to an ASIO driver like FlexASIO**. How?
        - Install `FlexASIO <https://github.com/dechamps/FlexASIO/releases/tag/flexasio-1.10b>`_ and `FlexASIO GUI <https://github.com/flipswitchingmonkey/FlexASIO_GUI/releases/tag/v0.35>`_
        - Below is the ``FlexASIO.toml`` I end up with after configuring FlexAsio GUI for 4x4 operation and writing it to the default location (you can't use this directly due to the german device names probably, but you should end up with something similar from the FlexAsio GUI - there are plenty of guides on how to set this up on the web):

    .. code-block:: text

        backend = "Windows WASAPI"
        bufferSizeSamples = 256
        [input]
        device = "Mikrofon (2- Tiliqua)"
        channels = 4
        [output]
        device = "Lautsprecher (2- Tiliqua)"
        channels = 4

USB MIDI Host - Device is never powered up
------------------------------------------

In ``POLYSYN``, if your MIDI device never receives power from Tiliqua despite having ``usb-host=enabled``:
    - If you are using a USB-C (male) to USB-A (female) adapter in Tiliqua's host port, try inserting the adapter into Tiliqua *BEFORE* you plug your device into the USB-A (female) port.
    - If that still doesn't work, try a good `brand like this <https://www.anker.com/ca/products/b8731>`_ which is known to work, being careful to plug in the adapter into Tiliqua before the MIDI device.

    .. note::

        This is a known bug that manifests with rare combinations of adapters in firmware v1.2.1 and earlier. A fix `is linked here <https://github.com/apfaudio/tiliqua/issues/170#issuecomment-4551905560>`_ if you want to try it out already, but will be included in v1.2.2+!

USB MIDI Host - Device powers up but no response to MIDI events
---------------------------------------------------------------

- Try re-plugging the device or cycling the ``usb-host`` option while it is plugged in.
- **Device is a USB Hub:** You could be trying to use a MIDI device which has a built-in USB hub, that is, the device has a built-in USB hub, and the MIDI device is behind it. **Tiliqua does not support this**. This is rare, so far I only saw this on a Boss RC-600 Loop station, because it has a built-in sound card and MIDI device behind an integrated USB hub. **In such cases I suggest using DIN/TRS MIDI instead**. You can check this on Linux in dmesg or in Windows in device manager.

USB MIDI Host - Device powers up but MIDI events are glitchy / have missing notes
---------------------------------------------------------------------------------

- There was a **known bug in POLYSYN v1.1.1 and earlier** with how Sysex and Clock messages were handled. This is now fixed in the latest versions.

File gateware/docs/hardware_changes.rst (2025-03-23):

Changelist
##########

There were some Tiliqua hardware released before the production R4 version. This page serves as a brief history of the differences between these versions, as well as any changes in post-production batches.

Tiliqua R4
==========

First production hardware release.

    - **SoldierCrab R3** FPGA SoM (LFE5U-25F, 1.8V 32MByte oSPIRAM)
    - **Tiliqua R4** motherboard and front panel.
    - **eurorack-pmod R3.3** audio interface.

R4 changes (compared to R3)
^^^^^^^^^^^^^^^^^^^^^^^^^^^

    - Add external PLL SI5351 and route 2x clocks to ECP5 (useful for EMC as it supports spread-spectrum, also for runtime clock/resolution switching).
    - Add series 27R/33R on all FFC lines to reduce radiated emissions.
    - Pinswaps to ensure external PLL is routed to true ECP5 clock input pins:
        - FFC_SDIN1: 44 -> 42
        - ENC_B: 40 -> 12
        - ENC_A: 42 -> 8
        - PLL_CLK1 -> 40 (removed: spare FPGA to RP2040 line)
        - PLL_CLK0 -> 44 (removed: spare FPGA to RP2040 line)
    - Route 4 new ex0/ex1 pins to RP2040 spare pins (shared with expansion connectors)
    - Swap RP2040 SPI flash for 128MBit part
    - Put spare RP2040 I2C pins on main tiliqua-mobo I2C bus.
    - Switch from 4L stackup to 6L stackup to improve SI/EMC.

Tiliqua R3
==========

Another hardware revision that some beta testers have. Only 5 were produced.

    - **SoldierCrab R3** FPGA SoM (LFE5U-25F, 1.8V 32MByte oSPIRAM)
    - **Tiliqua R3** motherboard and front panel.
    - **eurorack-pmod R3.3** audio interface.

R3 changes (compared to R2)
^^^^^^^^^^^^^^^^^^^^^^^^^^^

    - Pinswap all DVI pins to true ECP5 complementary pairs.
    - Swap all tantalums for ceramics, clean up PSU routing, swap LDO for TPS7A91, add choke input capacitors
    - Delete unused LEDs (MIDI bottom-side)
    - Fix EDID +5V I2C bridge schematic and enable.
    - Adjust fuses: +12V ingress 200mA->350mA fuse, GPDI +5V NONE->50mA fuse (so USB host doesn't pop the fuse!)
    - Move encoder footprint 0.4mm in, midi 0.1mm out for 0.5mm shim washer on encoder
    - Pinswap ex0 / ex1 / ffc connectors for improved routing and SI.
    - Update LED current limiting resistors s/120R/220R
    - Swap rp2040 xtal to ABM8/15pF/1K (improve yield)
    - New M2.5 standoff footprint
    - Move 12V ingress connector in 1.5mm so we can better fit in skiffs.
    - Switch from 1.6mm to 1.2mm PCBA stackup for mechanical reasons (and improve usb2 connector yield)
    - (panel) fix DVI connector cutout
    - Add 2x spare pins for RP2040/ECP5 I2C (no pullups)
    - Layerswap In1 / In2 (move GND closer to SMPS)
    - Add flip-flop on CODEC PDN pin (allows for soft-mute when swapping bitstreams)

Tiliqua R2
==========

This was the first hardware revision that some beta testers have. Only 5 were produced.

    - **SoldierCrab R2** FPGA SoM (LFE5U-45F, 3.3V 16MByte HyperRAM)
    - **Tiliqua R2** motherboard and front panel.
    - **eurorack-pmod R3.3** audio interface.

Tiliqua R1
==========

This prototype was shown at SuperBooth 2024. It was never shipped to anyone.

    - **SoldierCrab R1** FPGA SoM (LFE5U-45F, 3.3V 16MByte HyperRAM, no USB2 PHY)
    - **Tiliqua R1** motherboard and front panel.
    - **eurorack-pmod R3.3** audio interface.

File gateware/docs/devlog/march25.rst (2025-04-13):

[Devlog 1] EMC Adventures
===========================

.. note::

    *Thanks for dropping by! Tiliqua is an open-source project (see* :doc:`../foss_funding` *). Feel free to join the discussion (see* :doc:`../community`) *or join our* `mailing list <https://apf.audio>`_.

What a crazy last couple of months! I've been super busy bringing up the Tiliqua R4 (latest) hardware revision and getting it ready for production. The trickiest aspect was getting it through EMC testing, so this will be our focus today.

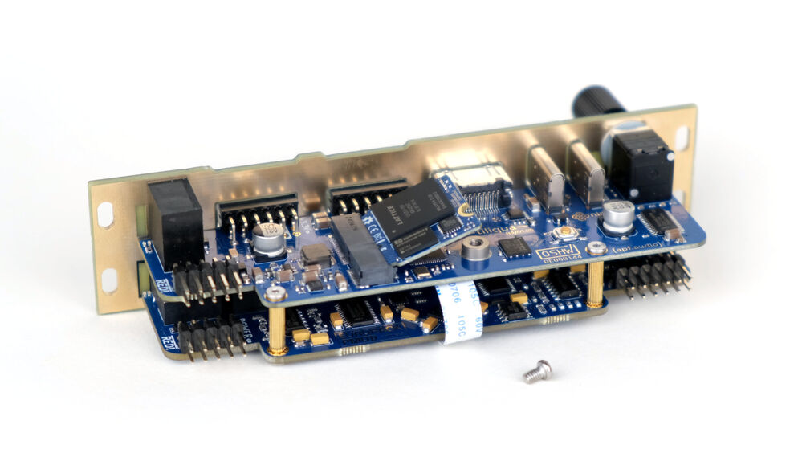
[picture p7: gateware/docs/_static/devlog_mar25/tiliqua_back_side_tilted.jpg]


New Features
------------

Before we dive deep into EMC, a quickfire list of unrelated wins from the last couple months:

- **R4 Hardware Diagrams**: I put together some detailed hardware diagrams of how the different bits of Tiliqua connect together, you can find them under :doc:`/hardware_design`.
- **Self-calibration**: Tiliqua can now semi-automatically calibrate its own CODEC for better control voltage tracking, you'll find the gruesome details under :doc:`/calibration`.
- **Bitstream Archives**: The format used for sharing and flashing user bitstreams is implemented and relatively stable now, this means you can share a single file which contains everything a project needs (bitstream, firmware, images, description of the contents). Gruesome details under :doc:`/bootloader`.
- **Parallel builds**: It's now possible to build all the Tiliqua projects simultaneously, which reduces the build time from about 15min for all projects (about 30 bitstreams) to about 5min on my machine. Try this out with `gateware/scripts/build_bitstreams_soc.sh <https://github.com/apfaudio/tiliqua/blob/main/gateware/scripts/build_bitstreams_soc.sh>`_!
- **Menu system refactor**: The Tiliqua menu system has been `completely rewritten <https://github.com/apfaudio/tiliqua/pull/85>`_ , which should make it much easier to modify it for your own purposes. I plan to write a short tutorial on how this works soon.

In this update
--------------

- **R4 Hardware & EMC**: A lot of work went into getting Tiliqua ready for EMC testing, I'll go through some lessons learned.
- **Dynamic Clocking**: The latest revision adds an external PLL, useful for EMC (spread spectrum) and dynamic resolution switching. We'll cover this below.
- **100% Amaranth**: Until recently there were some core Tiliqua components (especially audio CODEC initialization, calibration, the video subsystem) that were still re-using Verilog cores. These are now all removed and `ported to Amaranth <https://github.com/apfaudio/tiliqua/pull/89>`_, which should make the codebase easier to understand!

CE and FCC
----------

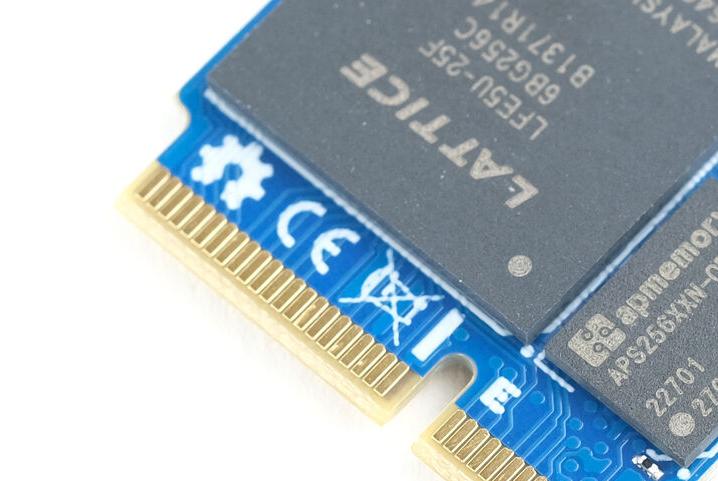
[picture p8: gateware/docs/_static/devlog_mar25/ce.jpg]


Any kind of electronic product sold in the EU must have evidence that it meets the requirements for a CE mark, in the US the (almost) equivalent mark is FCC. For a eurorack module like Tiliqua, there 2 most interesting sets of standards:

- EMC: There are hundreds of standards related to EMC (Electromagnetic Compliance: radio emissions and static discharge), however only a few are relevant to a low-voltage musical instrument like Tiliqua.
- RoHS: Restrictions on Hazardous Substances - this means that we are not using any nasty chemicals or leaded solder for example. Usually no testing is required to meet this, you just collect documentation for every single component and assembly step of your product and make sure that each part meets RoHS.

If you go to a test lab they will tell you exactly which standards are relevant to your product. For something like a Eurorack Module, it's the emissions requirements (radiated and tolerated radio emissions) and ESD immunity (simulated sparks from fingers) that are the most challenging.

The Setup
---------

Example system
**************

At a test lab, you are expected to bring a self-contained test system with your product in use. This means in the end it is not just your Eurorack module that must meet EMC, but the entire system, including the mains cable!

For Tiliqua's testing I put together a small system like this, including not just the Tiliqua but also a screen module, display cable, headphone interface and so on:

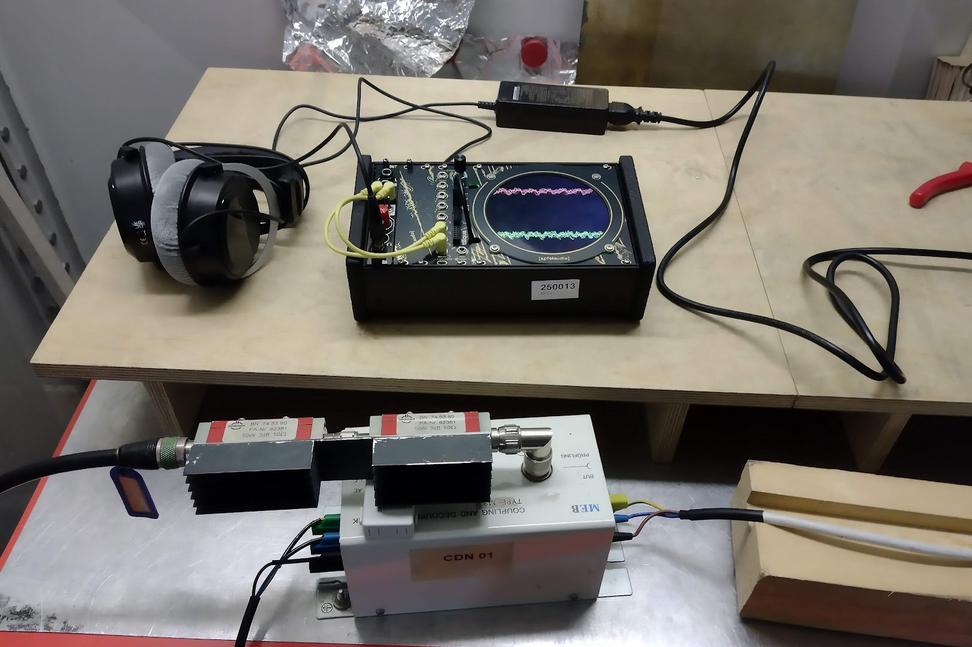
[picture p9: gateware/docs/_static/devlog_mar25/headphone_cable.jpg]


    Small example system with headphones and mains adapter in the professional test lab.

The other modules, mains adapter, case, and DC-DC converters inside the case will all affect the test result. So, if you're going to a test lab for the first time, best to bring spares to swap out for each part.

Pre-test chamber
****************

Time at a test lab can be expensive. To save time and money, I built a small EMC test chamber using a slighty modified version of the `open-source design you'll find here <https://essentialscrap.com/tem_cell/>`_. Here's a picture of my build:

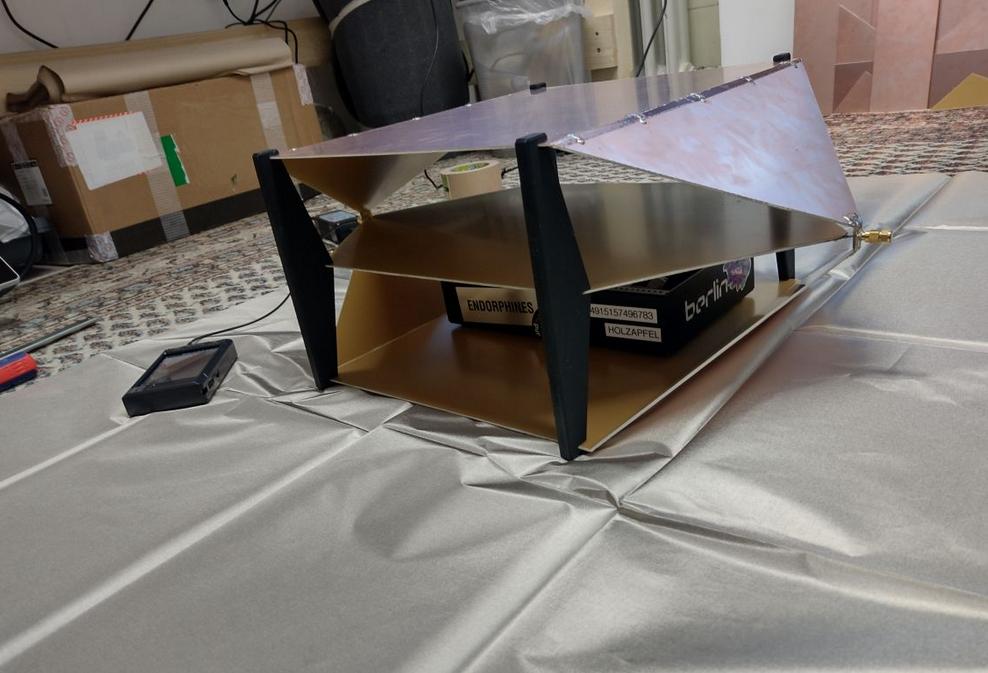
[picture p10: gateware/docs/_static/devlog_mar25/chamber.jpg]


   Homebrew TEM cell with TinySA pro and example system inside it.

The chamber is called a "TEM cell", and you can visualize it like an oversized transmission line - a huge coax cable, which you can put your device into to take broadband measurements. A chamber like this is even allowed as an official measurement method (if you get a much more expensive and calibrated one!).

Spectrum Analyzer
*****************

For a cheap spectrum analyzer, I decided to use a TinySA Pro.

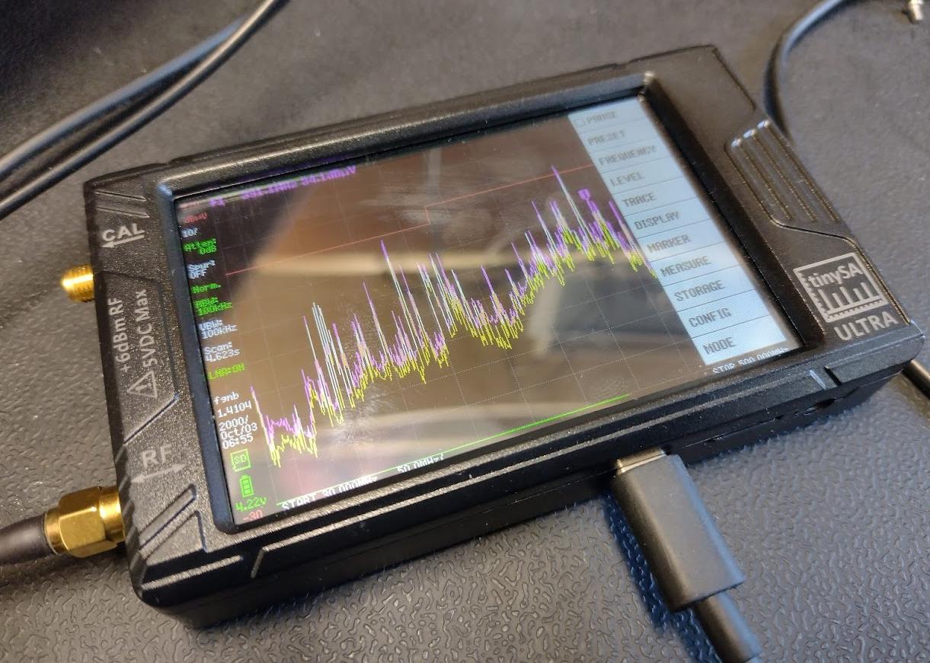
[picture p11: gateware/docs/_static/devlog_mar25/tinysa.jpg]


With a TEM cell, there are tables you can use to convert measurements from a cell like this into (rough) far-field measurements, to get an idea of whether you would pass the 'real' test or not. You can find lots of details in `Petteri Aimonen's repository <https://github.com/PetteriAimonen/tem-cell/tree/main>`_.

In my case, I used the TinySA `preset found here <https://github.com/PetteriAimonen/tem-cell/blob/main/Model_L500mm_W350mm_H200mm/TinySAUltra_Preset.prs>`_ to check my own measurements against the rough EMC standard thresholds. This results in a nice red 'fail line' that is helpful to identify the problematic areas (you can see the red line in the photo above).

Note: I discovered the preset above requires firmware version v1.4104 to work properly, you might want to downgrade to that firmware version in order to use the preset

Dodgy sniffer probe
*******************

To help localize the source of radio noise, I put together a super-dodgy sniffer probe using a couple of enamel wire loops:

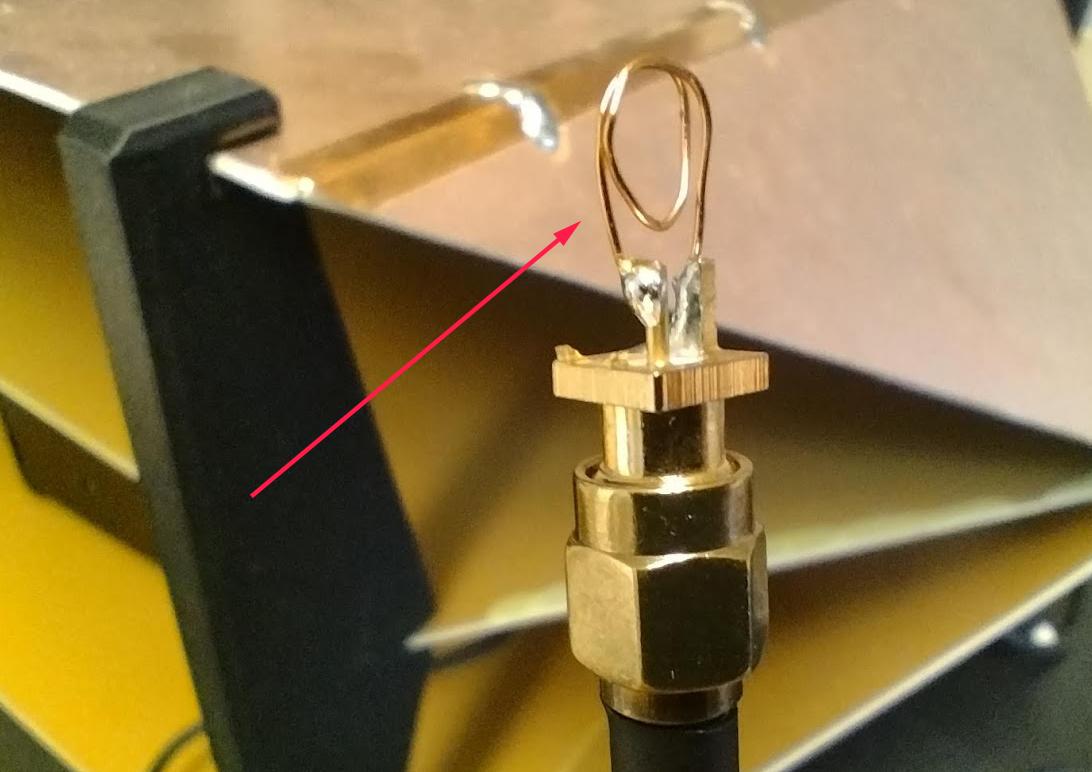
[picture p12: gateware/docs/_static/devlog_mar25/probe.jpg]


In the end, this probe did not end up being very useful, it worked, but often seemed to point at an area of the board that had nothing to do with the source of the noise. So I'd strongly lean toward just using a TEM cell, the sniffer probe did not help much.

LISN
****

For measuring conducted noise (noise travelling back up the eurorack power cable), I built a small LISN (line impedance stabilization network) which is used to measure the amount of conducted noise (i.e emitted on the power supply cables). You can build one yourself following the `open-source design found here <https://github.com/bvernoux/EMC_5uH_LISN>`_. It looks like this:

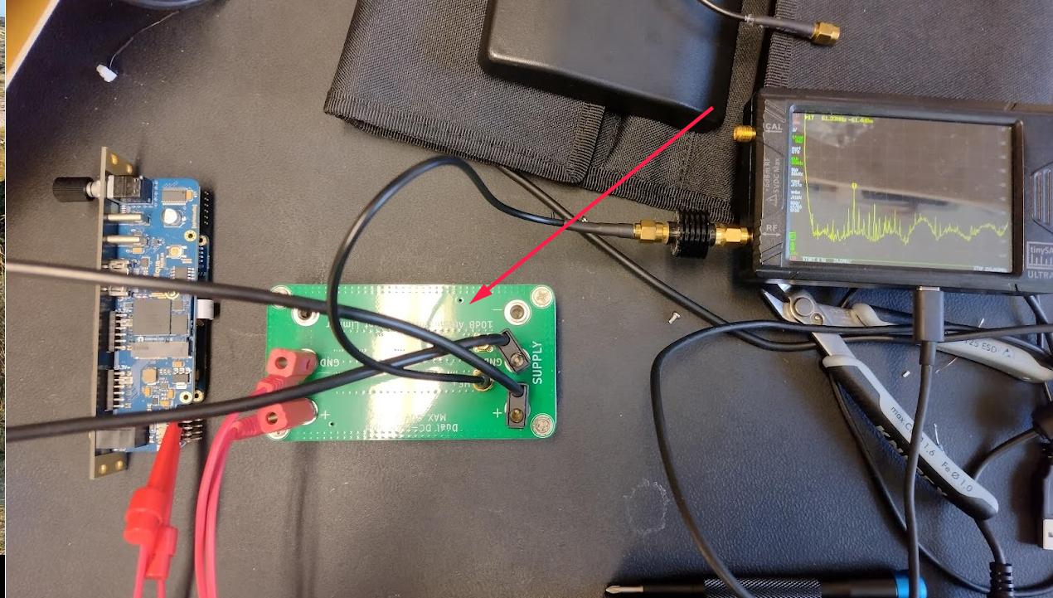
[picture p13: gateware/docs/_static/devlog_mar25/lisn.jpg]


Pre-testing: Findings
---------------------

Fail!
*****

On first measuring Tiliqua R2, things did not look so great. In the TEM cell, radiated emissions looked like this:

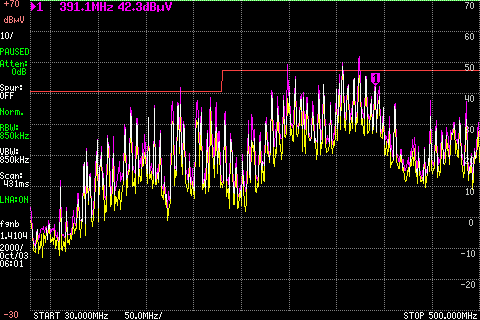
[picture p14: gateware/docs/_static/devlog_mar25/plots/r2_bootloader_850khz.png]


Gross failures, mostly at harmonics of the audio master clock (12.288MHz) and the video master clock (37.4MHz in this case). Conducted emissions with the LISN were not much better:

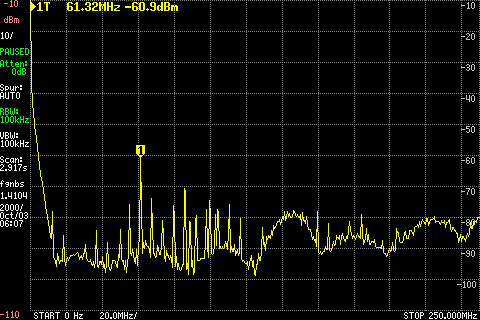
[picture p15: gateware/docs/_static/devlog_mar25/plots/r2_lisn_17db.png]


For conducted emissions, our limit is roughly -40dBm. As we measure worse than -60dBm with a 17dB attenuation in-line, this is dangerously close to the limit.

.. note::

   In a eurorack system, there is a bus board and mains adapter between our module and the rest of the world, so likely the conducted noise would not be visible at the mains (and we wouldn't fail at a test lab), but it's still good to fix this so we don't conduct power-supply noise over to other modules in the system and degrade their audio performance.

Clearly, some work had to be done. But where to start?

Learning 1: SMPS input filtering
********************************

At the low end of our LISN plot, you can see some spikes and a wideband slice of spectrum suspiciously close to the switching frequency of the +5V switchmode regulator.

To address this, I added some extra input filtering on the +12V ingress, and then completely re-routed the entire SMPS section, using more polygons and being careful to keep all paths low-inductance. Here's a comparison of the routing on R2 vs. R4 in this section:

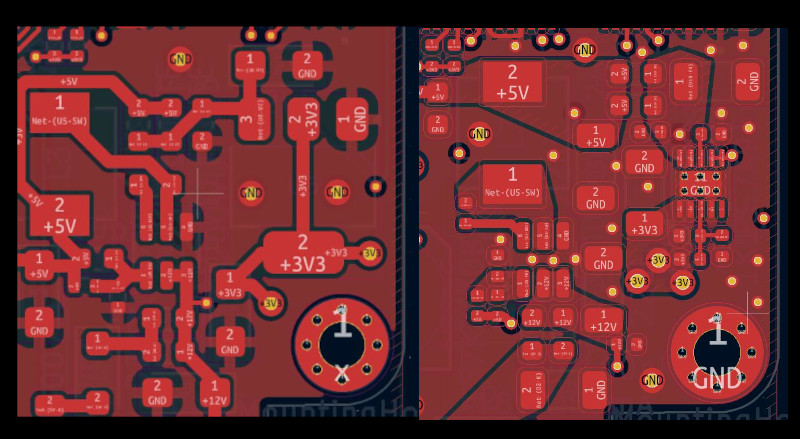
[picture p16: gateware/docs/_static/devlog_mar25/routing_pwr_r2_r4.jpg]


   Left: old routing (R2). Right: new routing (R4)

This made quite a dramatic difference. After this change, the conducted noise looks like this (peaks are around 20dB lower than before!):

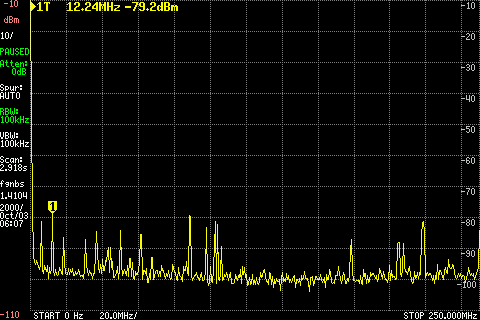
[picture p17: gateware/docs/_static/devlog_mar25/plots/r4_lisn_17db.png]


Learning 2: FPGA drive strengths, series resistors
**************************************************

In our initial radiated emissions plot, at various harmonics of 12.288MHz (audio master clock) and of 37.1MHz (video master clock), you can notice a bunch of emissions.

To address these, I tried to reduce the FPGA pad drive strength as follows:

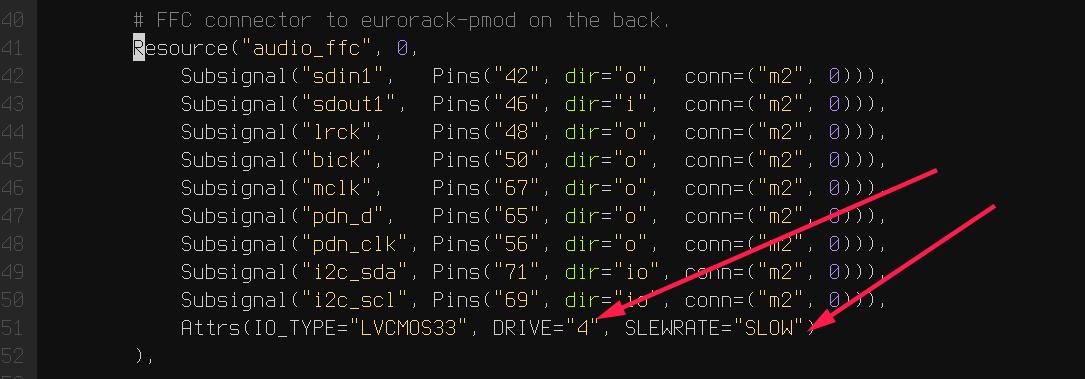
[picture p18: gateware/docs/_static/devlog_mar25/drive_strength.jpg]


   Reducing pad drive strength in Amaranth platform declaration.

This improved things, but we were still way over the limit. So on Tiliqua R3 I tried adding some extra series resistors on the audio clock/data lines for reduced slew rate:

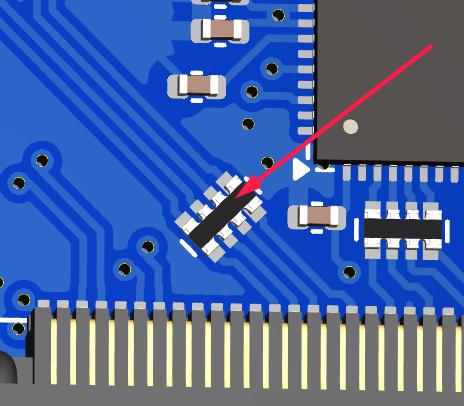
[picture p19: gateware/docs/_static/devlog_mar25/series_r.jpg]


   Series 33R resistors on audio clock/data lines.

These 2 changes got us *almost* under the limit line. But almost = risky. More work was needed.

Learning 3: Split ground planes
*******************************

Tiliqua's audio board uses split ground planes - that is, the analog and digital grounds are isolated with inductors. This is recommended in the CODEC datasheet, however there is some disagreement in the engineering community as to when it harms products vs. when it helps them.

One disadvantage of this approach is that it can negatively impact EMC - if anything couples to the isolated ground plane, it can resonate as an antenna. Turns out, this was exactly what was causing most of the emissions at 12.288MHz harmonics (master audio clock).

As soon as I shorted the isolated analog ground plane to Tiliqua's metal binding stubs:

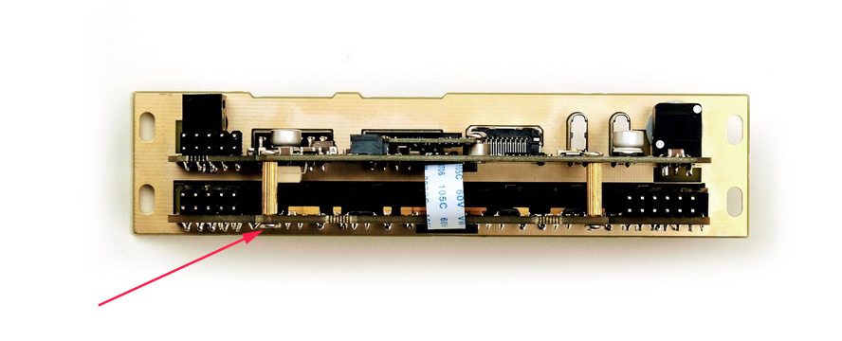
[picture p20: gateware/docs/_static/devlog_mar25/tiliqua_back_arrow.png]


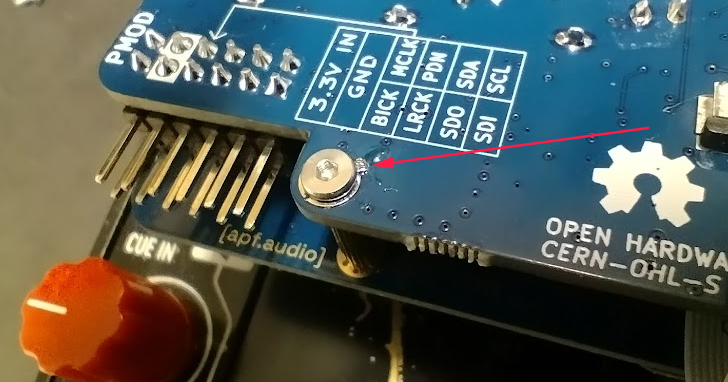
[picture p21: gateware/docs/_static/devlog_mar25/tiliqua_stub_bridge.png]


The emissions from 12.288MHz harmonics got almost completely squashed! Of course, I think performed a lot of testing to make sure the audio quality did not suffer, and suprisingly it made no difference. So this change was here to stay.

Learning 4: Spread Spectrum
***************************

Haunted by the above lessons and to make *absolutely* sure we would pass in the real test lab, I decided to add *another* EMC mitigation to Tiliqua R4 - an external spread-spectrum PLL. This allows the FPGA to have clocks which are modulated by some small percent (say 0.1% to 1% or so) at a low frequency (30kHz in our case). The consequence is that the energy in our harmonics is 'spread out' across the band, reducing the peak amplitude.

To demonstrate this effect, here is 2 captures, Tiliqua R4 with 2 different bitstreams, one configured with spread-spectrum at 0.1% and one with spread-spectrum at 1%:

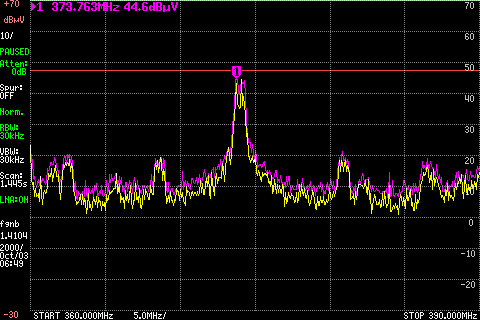
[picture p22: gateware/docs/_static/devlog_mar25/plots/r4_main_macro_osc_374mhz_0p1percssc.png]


   10th harmonic of video master clock with 0.1% spread-spectrum

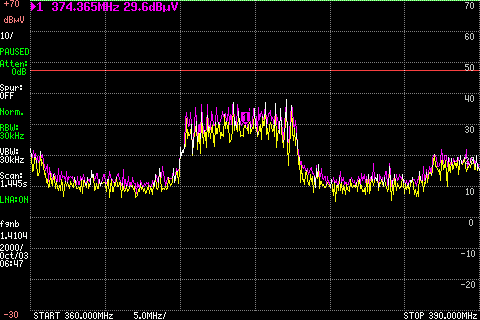
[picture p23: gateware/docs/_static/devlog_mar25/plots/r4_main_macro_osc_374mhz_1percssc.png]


   10th harmonic of video master clock at 1% spread-spectrum

It's not a magic bullet, but definitely makes a difference. Here you see a reduction in the peak amplitude of around 10dB.

This is a feature supported internally by some modern FPGA families, but the ECP5 does not have this feature (nor does any FPGA supported by the open-source FPGA tool flow, as far as we know). So we are essentially relying on the ability of the ECP5's *internal* PLL to lock onto a slowly frequency-modulating *external* PLL. In theory, this should depend on the ECP5 PLL's loop bandwidth as to what modulation depth should work, which is unfortunately undocumented. Fortunately, this arrangement seems to work fine in my testing.

Distraction: SI5351 Driver and Dynamic Clocking
***********************************************

EMC was not the only reason I decided to add an external PLL, there are 2 more reasons this made a lot of sense for Tiliqua:

- The ECP5-25 only has 2 built-in PLLs. This means we can't have separate PLLs for USB/RAM/audio/video, and means that we have to sacrifice either the accuracy of the audio or video clocks. Undesirable. An extra external PLL means we don't have to make this compromise.
- The ECP5's internal PLLs cannot be reprogrammed at runtime. This means that the display resolution or audio clocks are fixed after a bitstream has started. With an external PLL, this restriction is lifted. For tiliqua, dynamic resolution switching is a crucial feature, especially as we plan to distribute an optional screen with custom timings. Tiliqua should be able to detect which screen it is attached to and choose its resolution accordingly.

Getting the external PLL to work was not trivial. I had to:

- Make sure the si5351 was routed to the correct ECP5 pins (that is, they can be used as a PLL lock source)
- Write a driver for the si5351 spread-spectrum capabilities.
- Rework the Tiliqua clock tree / gateware so that the asynchronous external clocks generate internal resets and can drive internal signals appropriately.

The si5351 Rust driver (and test cases I added) was based on an open-source driver that I heavily modified such that it can support spread-spectrum configuration and more fine-grained divider settings. You can find my implementation `here <https://github.com/apfaudio/tiliqua/pull/87>`_ (it was based on this open source driver that had no spread-spectrum support and no test cases).

I won't go into more details here, but suffice it to say, if you build a bitstream for Tiliqua R4 now, all this is transparent to you, and you'll see a nice printout of the resulting clock tree:

.. code-block:: bash

    ┌─────────────[tiliqua-mobo]──────────────────────────────[soldiercrab]────────────┐
    │                                          ┊[48MHz OSC]                            │
    │                                          ┊└─>[ECP5 PLL]─┐                        │
    │                                          ┊              ├>[sync]     60.0000 MHz │
    │                                          ┊              ├>[usb]      60.0000 MHz │
    │                                          ┊              └>[fast]    120.0000 MHz │
    │ [25MHz OSC]─┐                            ┊                                       │
    │             └>[si5351 PLL]─┐             ┊                                       │
    │                (dynamic)   ├>[expll_clk0]────────────────>[audio]    12.2880 MHz │
    │                            └>[expll_clk1]─>[ECP5 PLL]──┐                         │
    │                                          ┊             ├─>[dvi]      74.2500 MHz │
    │                                          ┊             └─>[dvi5x]   371.2500 MHz │
    └──────────────────────────────────────────────────────────────────────────────────┘

This gives you a picture of how all the oscillators and PLLs both inside the FPGA SoM (soldiercrab) and on the Tiliqua motherboard fit together. Most clocks go through an internal ECP5 PLL, except the audio clock, which is routed straight to the fabric.

The dynamic clock tree settings get saved into the bitstream manifest (describing user bitstreams), so the bootloader can dynamically configure the external PLL based on what any particular user bitstream wants.

Lab-testing: Findings
---------------------

To see the effect of applying all the above changes, here's a control (empty chamber), before (R2 hardware) and after (R4 hardware) comparison:

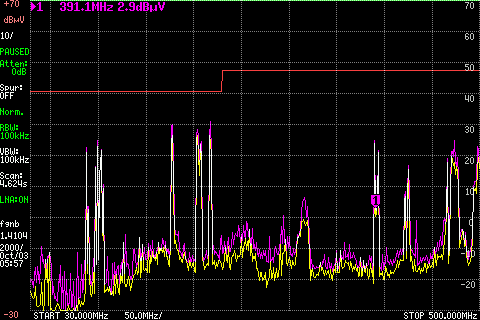
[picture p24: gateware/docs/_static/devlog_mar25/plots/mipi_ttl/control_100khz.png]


    Control (empty chamber)

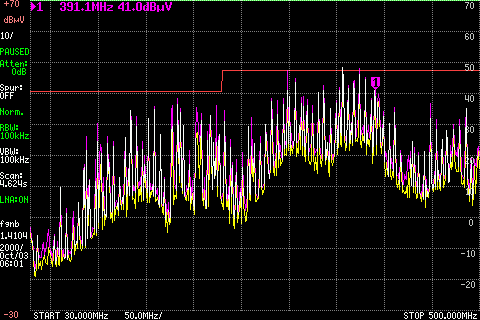
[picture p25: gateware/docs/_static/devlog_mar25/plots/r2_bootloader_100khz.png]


    Tiliqua R2 (none of the above learnings applied)

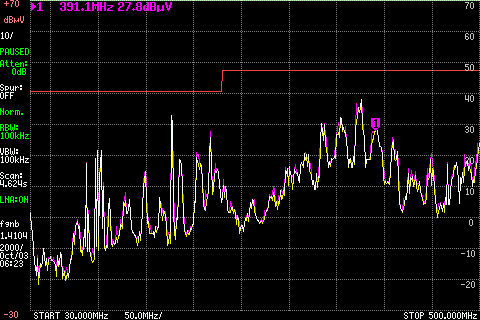
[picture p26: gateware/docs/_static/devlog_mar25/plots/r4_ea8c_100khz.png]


    Tiliqua R4 (all of the above learnings applied)

Interestingly, in these plots it is the 300-400MHz region that seems the 'worst', however, as we'll see later, in the real test lab this region was not problematic at all and in fact the 100-200MHz region was more critical, likely due to coupling into the long headphone cable.

Anyway, after all this effort, it was finally time to take Tiliqua to an EMC test lab! To spoil the result, we passed! But it was not without hiccups.

Learning 5: Long cables
***********************

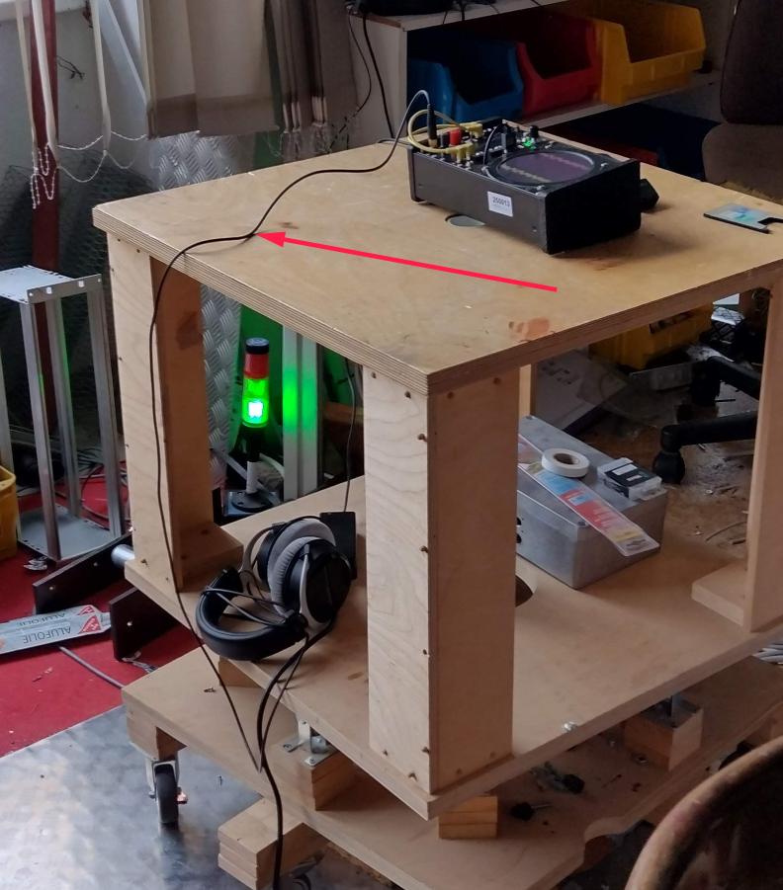
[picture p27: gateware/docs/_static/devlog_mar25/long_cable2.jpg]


One thing that surprised us was how much the headphone cables going into our Eurorack system were affecting the results. It did not bring us over the limit lines (fortunately), but shortening or lengthening the headphone cable made quite a difference to the radiated emissions.

So, be careful with this. In theory, your device should work with any sane length of headphone cable, but if you want to be more certain that things will go well, it might be safer to use something shorter than the 3 meter headphone cable I was using. 3 meters is right in that 100-200MHz resonance where we were close to failing with EMC.

Additionally, long cables are impossible to simulate with a small test chamber (or custom TEM cell like we have).

Learning 6: ESD is no joke
***************************

Part of CE testing involves zapping the DUT with an ESD gun. I was especially scared of this given Tiliqua has touch-sensitive jacks where we have the pins of a touch IC exposed to the outside world. Fortunately, I followed Cypress' recommendations of having a large series resistance to the touch pads, which is supposed to mitigate any ESD frying the touch IC. Normally, adding TVS diodes is a no-brainer for this, but since they add extra capacitance, my fear was that they would negatively effect the touch sensing capabilities.

Surprisingly, however, I discovered that zapping the touchpads with extremely high voltage (i.e. a bit above the standard), the touch sensors would momentarily stop working. After some investigation, I discovered the zap was actually erasing the NVM (non-volatile memory) in the touch IC, the Tiliqua firmware was then detecting this and reprogramming the NVM.

So: be prepared. Add watchdogs to your code. ESD is no joke.

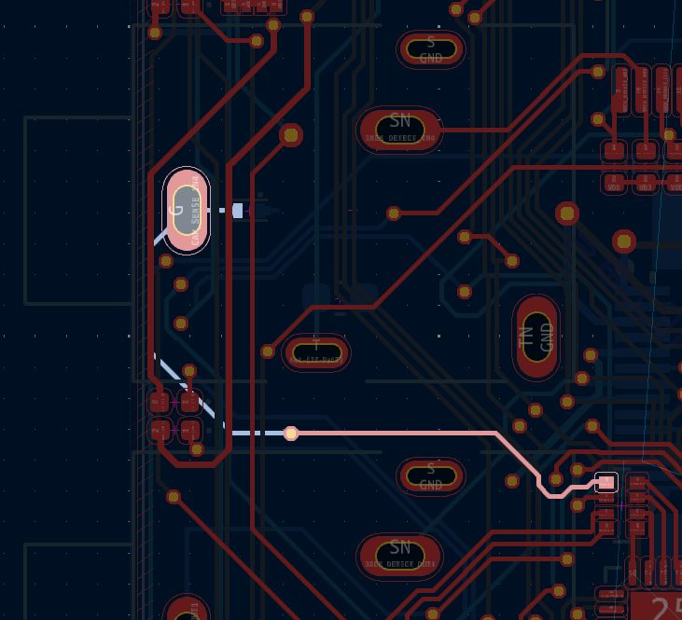
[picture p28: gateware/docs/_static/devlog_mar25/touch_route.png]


*Routing of one of the touch pads through a series resistor*

Learning 7: TEM cell vs. real far-field measurements
****************************************************

Because all our pre-testing was in a custom-built TEM cell, I found it interesting to compare the spectrum from our "super-cheap" option with the real thing. In general, we noticed the 'real' measurements were about 5-10dB lower in the 300MHz+ region than the TEM cell, but in the 100-200MHz region, the real measurements were about 5-10dB higher than the TEM cell (!). I think the reasons are:

- The long headphone cable, which couldn't be contained inside the TEM cell.
- The Eurorack case is a bit too big for this size of TEM cell. Ideally our chamber would be larger.
- Imperfections in the TEM cell construction itself.

*(Note: I am not sure if I am allowed to publish the lab measurements here, hence the quantitative description of the differences in plots)*

EMC: Conclusion
---------------

Even though our cheap pre-compliance chamber was not so accurate, it allowed us to figure out which parts of the design needed changes early and squashed the need for doing a second visit.

Tiliqua R4 is now, to our knowledge, EMC compliant. Although this was a LOT of effort, we are confident that all the changes will result in a more robust instrument that stands the test of time, and doesn't interfere with anything else in your rack.

Bonus: New Amaranth Cores!
--------------------------

We're happy to report that we've finally finished porting *all remaining verilog* to Amaranth! This will hopefully decrease the learning curve when getting started with this project. Specifically, we rewrote the following:

- The audio I2S controller gateware and online sample calibration module `(link to PR 82) <https://github.com/apfaudio/tiliqua/pull/82>`_
- The I2C controller gateware for all I2C peripherals on the audio board (LEDs, jack detect, touch detect, codec init) `(link to PR) <https://github.com/apfaudio/tiliqua/pull/72>`_
- The display serializer (tmds) and video generator `(link to PR 89) <https://github.com/apfaudio/tiliqua/pull/89>`_

As a result of this rewrite we're also using a few percent less area of the ECP5. So more space for other things!

Note: Our CPU is as of now the only non-amaranth component (SpinalHDL), however VexRiscv has proven faster and has better area usage than any other core we could find. For this reason, we plan to stick to VexRiscv for the CPU (and perhaps VexiiRiscv in a few monts).

Bonus: Crowd Supply & Trade Tariffs
-----------------------------------

Obviously everyone in our industry is trying to figure out what to do with the ongoing trade war. For us, our plan was always to launch through CrowdSupply. But with these tariffs, this would imply an undesired price hike. We're currently talking to Crowd Supply to see what our options are here.

If we launch through Crowd Supply, EU customers (and me of course) would have to eat the cost of US tariffs and then potentially any reciprocal tariffs the EU may set up - which makes zero sense as this is a project centered in the EU. I'm currently working hard to figure out what the best path forward is here and will provide an update once I have more information.

Acknowledgements & further reading
----------------------------------

- Massive thanks to NLnet for supporting this project (:doc:`../foss_funding`).
- Petteri Aimonen's `open-source TEM cell design  <https://essentialscrap.com/tem_cell/>`_ saved loads of time and worked great.
- bvernaux' `open-source LISN design <https://github.com/bvernoux/EMC_5uH_LISN>`_ saved lots of time and worked great.
- Mutable Instruments also has a `nice practical overview <https://pichenettes.github.io/mutable-instruments-documentation/tech_notes/emc_certification_process/>`_ of the steps involved in EMC certification of Eurorack modules.

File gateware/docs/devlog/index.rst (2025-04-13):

Development Blog
################

Here you will find detailed project updates and lessons learned.

.. toctree::
   march25

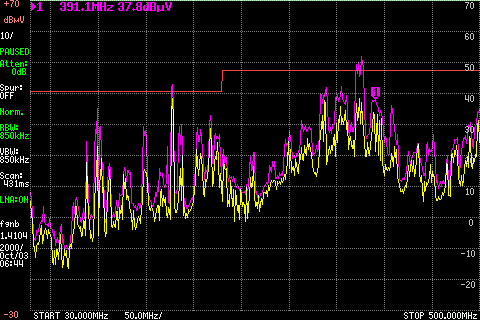
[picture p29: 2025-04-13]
gateware/docs/_static/devlog_mar25/plots/r4_main_macro_osc_850khz.png

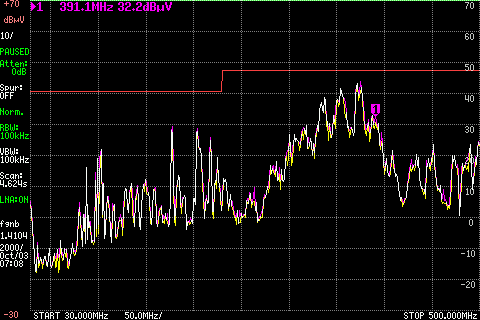
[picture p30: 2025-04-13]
gateware/docs/_static/devlog_mar25/plots/r4_main_bootloader_missingshort_100khz.png

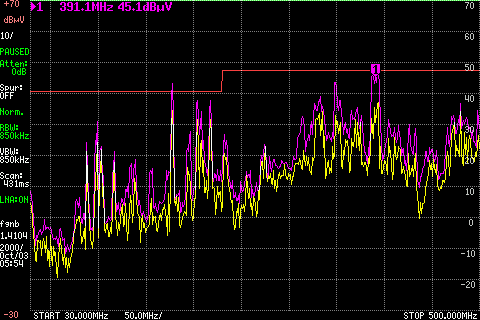
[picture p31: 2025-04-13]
gateware/docs/_static/devlog_mar25/plots/mipi_ttl/mipi_850khz.png

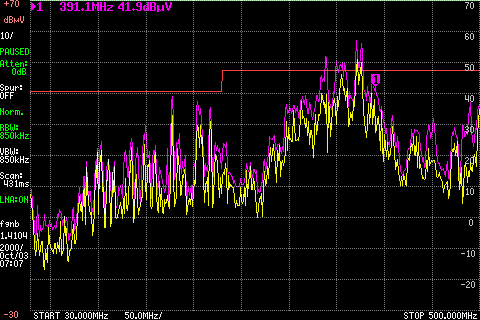
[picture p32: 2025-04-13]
gateware/docs/_static/devlog_mar25/plots/r4_main_bootloader_missingshort_850khz.png

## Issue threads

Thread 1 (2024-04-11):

bringup // 04.24

schnommus, 2024-04-11:
BUGS found
- rp2040 doesn't enter bootloader:
  - fix: rp2040 assumes 2V5 rail that doesn't exist. Fix: bridge C7 + C10
- rp2040 doesn't exit bootloader:
  - fix: too much pull on SPI flash CS. Fix: remove C17
- fpga won't self-configure
  -  fix: applecrab initn pd should be removed
- 3V3 line is noisy and ~3.15V instead of 3.3V
  - Switch to 5V buck with post-regulator (linear)?
- Power from USB doesn't work with jumper set
  - Remove this feature OR add single -5V supply such that analog rails work off of USB only (test swing?)

BRINGUP done:
- test hyperram @ full-speed (240MB/sec) reliable
- test fpga flash / config / readback
- test RP2040 debugging
- test USB2 PHY
- test eurorack-pmod interface and noise

ADMIN:
- take some nice pictures, publish repo as UNDER CONSTRUCTION
- get open hardware certification ID
- get open USB PID/VID
- next revision: get CE cert and gather docs
- 2xusb // 90deg + uhdmi + encoder + sd (opt)

Closed 2024-06-10.

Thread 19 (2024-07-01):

Known Issues: Tiliqua R2.0

schnommus, 2024-07-01:
Some known issues and notes on bringing up the R2.0 beta units:

- **WARN: always use the tiliqua mobo bus power ingress**. The other 12V bus power (going straight into eurorack-pmod) has no polyfuse.

## `eurorack-pmod` PCBA
- Capsense  IC stays in reset if jack 2 (starting at 0) is inserted before cold powerup. Workaround is already in gateware, see https://github.com/apfelaudio/eurorack-pmod/issues/59

## `tiliqua-mobo` PCBA
- Polyfuse too low for ~500mA max. current draw when Tiliqua is used to source current in USB host mode.
    - No USB host example projects yet, need this for validation
    - I tried drawing this kind of current, nothing blows up. The tiliqua will just turn off and the built-in polyfuse resets 30sec later.
    - Using the eurorack-pmod power ingress instead is an easy workaround for host testing
- Encoder locating pin sticks out too far.
- V-Score slightly too close to panel, causing tilt on mobo PCBA. A shim washer on the encoder should also help with this.

## `soldiercrab` PCBA
- LEDs are too bright, current limiting resistors should be larger.
- Gets a bit warm (but not too hot to touch). Ground mounting hole on both sides for better heatsinking & shielding. Switching to smaller ECP5/PSRAM should also help with this alongside 3V3 -> 1V8 on the PSRAM/USB PHY rails.
- Increase copper clearance at edges to reduce dimensions on all sides by ~0.2mm

## `panel` PCBA
- Plate slots for DVI/USB for better shielding
- Fix DVI panel cutout, it's close but not perfect
- Fix rounding on the LED encoder ring cutout.

Closed 2024-08-04.

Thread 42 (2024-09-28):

Remove & rewrite `eurorack-pmod`/`tmds_encoder` verilog dependencies

vk2seb, 2024-09-28:
There are some small verilog dependencies remaining, that should be ported to Amaranth.
- `gateware/vendor/dvi`: contains a TMDS encoder used for video output
- `gateware/deps/eurorack-pmod`: contains sample calibration, I2S driver, I2C state machine for LEDs + touch sensing.
- VexRiscV is also a non-amaranth dependency, however I tried both Sentinel and Minerva soft-core CPUs (amaranth projects) and unfortunately the performance/area simply is not up to par with Vex yet. So this dependency will stay for the foreseeable future.

Particularly the `eurorack-pmod` dependency should be ported soon as:
- It shares a lot of functionality with the SoC's I2C driver that could be combined, to reduce LUT usage.
- The ADC/DAC calibration should be performed by the SoC by twiddling some registers. For this it makes sense to have all that logic in pure Amaranth.

vk2seb, 2025-05-17:
All verilog dependencies outside of the SID core and Vex are now removed.

Closed 2025-05-17.

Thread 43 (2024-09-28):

Tiliqua R3 Motherboard: changelist (WIP)

vk2seb, 2024-09-28:
## required
- ~~+5V SMPS: increase polyfuse ingress current for +VUSB host output~~
    - ~~polyfuses on all external power outputs? IGNORE~~
- ~~+5V SMPS + 3V3 linear: gets pretty hot - increase LED pull downs?~~
	- ~~Swap all tantalums for 1206 X5R ceramics~~
	- ~~More vias + ground standoff post~~
- ~~+/- 12V ingress: check noise, add filtering~~
- ~~USB2: review/revise footprint~~
    - ~~And **reduce PCB thickness** - 1.2mm?~~
- ~~Encoder: shuffle back (maybe shim between encoder + panel)~~
- ~~GPDI: pinswap PMOD routing for cleaner GPDI routing~~
- ~~GPDI: current limit +5V out (or switchable?)~~
- ~~GPDI: Fix PCA VREF2 resistor, add ability to disable EDID I2C bridge using EN line.~~
- ~~RP2040: switch to mfg-recommended XTAL (optional)~~
- ~~SC3: MicroMod Hole alignment is slightly off. Center it.~~
- ~~M2: reflowable standoffs, change source~~

## nice
- RP2040: add LEDs
- RP2040: route encoder pins to spare hi-Z inputs
- RP2040: put it on the local and eurorack-pmod I2C buses
- RP2040: add ability to control PDN (I2S?)
- RP2040: connect some pins to PMOD output for internal Vex JTAG?
	- Could even use the same JTAG pins? worth testing.
	- Extreme: move JTAG loopback to SC itself?!
	- Try this bodge on old Tiliqua
- soldiercrab: second standoff hole for future?
- soldiercrab: Route new I2C pins to RP2040 (or somewhere else)

Closed 2025-05-17.

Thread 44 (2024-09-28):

`DelayLine` should use L2 cache + PSRAM as a backing store

schnommus, 2024-09-28:
At the moment all the examples using `DelayLine` use DPRAM as a backing store, which quickly exhausts the FPGA resources (this is e.g. 40% of the DPRAM in the `polysyn` bitstream).

Likely we want something like `DelayLineWriter` and a `DelayLineTap` components (single writer, multiple-reader is the common use-case for delay lines). Given the PSRAM access latency is high, achieving this will also require writing a custom cache.

Probably `WishboneL2Cache` from `tiliqua/cache.py` could be used for this if we add support for read bursting on the memory interface (currently it can only fill 1 word at a time, which is not good for memory bandwidth at all)

schnommus, 2024-09-29:
Got this working and made a quick ping-pong delay using 2 psram-backed delaylines: https://github.com/apfelaudio/tiliqua/tree/seb/psram-delayln

Next step is to attack L2 cache (to memory) bursting. At the moment 2 delaylines with 2 taps consume ~10% of the overall memory bandwidth, but with correct cache bursting this should be much lower.

schnommus, 2024-10-02:
Mostly merged now: https://github.com/apfelaudio/tiliqua/pull/48

All that's missing is improving the the memory bursting behavior of `WishboneL2Cache`.

Closed 2024-10-05.

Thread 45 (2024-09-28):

`bootloader` should show bitstream properties from SPI flash

schnommus, 2024-09-28:
Currently the bootloader just supports selecting 1 of N bitstreams, but has no idea what is in each slot.

The `bootloader` bitstream should show the true bitstream name in the boot menu by reading it from the SPI flash.
One possible approach:
- Prepend a comment field to each bitstream with the project name + options during build (you can do this with `ecppack`)
- In the `bootloader`, use this comment field from SPI flash to show the bitstream name

schnommus, 2024-09-29:
I was able to get memory-mapped SPI flash access working on SoldierCrab R3 based on the existing work in `luna-soc`: https://github.com/apfelaudio/tiliqua/tree/seb/spiflash

Looking at the openFPGALoader implementation, it seems the comment fields of the `.bit` file are skipped before the bitstream is actually written to flash: https://github.com/trabucayre/openFPGALoader/blob/master/src/latticeBitParser.cpp#L96

So we can't directly read the bitstream metadata from SPI flash. However, we can probably trivially append something useful that the bootloader can use.

schnommus, 2024-10-03:
It looks like if you add `--file-type raw` to the `openFPGALoader` invocation, it won't touch the bitstream header, and the ECP5 still seems to configure fine from such a bitstream with the comments still present. Which is nice, so we can in theory 'hide' the name of each bitstream inside the bitstream itself.

The downside of course is that this bypasses the usual checks that the device ID matches the bitstream, however we could probably verify this in the bootloader itself...

Either that, or add an upstream command line option to `openFPGALoader` to not skip the start of the bitstream (I just tested modifying this line and it also works) https://github.com/trabucayre/openFPGALoader/blob/773a7c805d1bfda66bc73c83afd6e0f72e58e78b/src/latticeBitParser.cpp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

Closed 2024-11-07.

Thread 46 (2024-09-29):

Reduce FIR size in `Resample` interpolators

schnommus, 2024-09-29:
The `Resample` DSP component instantiates quite large FIR filters for upsampling beyond 4x, this can quickly eat FPGA area and is heavily used for scope plotting (interpolating lines from points).

We can reduce the area and time footprint quite a bit by adding additional `Resample`, for example one which uses a CIC or Boxcar filter for the primary anti-aliasing filter.

Maybe useful: https://tomverbeure.github.io/2020/09/30/Moving-Average-and-CIC-Filters.html

schnommus, 2024-10-13:
Now that we have a true polyphase resampler that infers BRAM correctly, this is essentially done: https://github.com/apfelaudio/tiliqua/pull/60

I was also able to reduce the multiplier from 8 to 5 and get similar performance

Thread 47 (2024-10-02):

Revisit gateware/firmware license choice

schnommus, 2024-10-02:
Currently this project has some dependencies that force us to use `CERN-OHL-S` on gateware, firmware and hardware components of this project.

However, I think the project may be better served by a more relaxed license choice, particularly on the gateware and firmware (perhaps BSD or OHL-P).

The hardware license I am not planning changing from `CERN-OHL-S`, this issue only concerns itself with gateware and firmware licenses.

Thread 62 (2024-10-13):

Use `cxxrtl` as SoC simulation backend.

schnommus, 2024-10-13:
Working proof-of-concept: https://github.com/apfelaudio/tiliqua/pull/56

I tried `cxxrtl` in the past as a simulation backend, however it was extremely slow due to a regression in LLVM. Once this regression is commonly 'gone' in most commodity linux distributions, we should consider switching to `cxxrtl` everywhere.

Upstream bug: https://github.com/YosysHQ/yosys/issues/4419

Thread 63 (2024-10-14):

Enforce non-overlapping `MemoryMap` for all DMA peripherals, `DelayLines`, etc.

schnommus, 2024-10-14:
Currently Tiliqua SoCs may contain quite a few DMA peripherals that have access to PSRAM (`DelayLine`, `FramebufferPHY`, `Stroke` and so on). There is no enforcement that these peripherals exist in the correct regions and/or are not unexpectedly overlapping.

For example, it's likely never desirable for the framebuffer to overlap with delay lines (even though this would be visually interesting). Similarly, delaylines should likely never have overlapping backing stores.

`amaranth-soc` provides [abstractions](https://github.com/amaranth-lang/amaranth-soc/blob/main/amaranth_soc/memory.py) to deal with this. We're currently using this only for the SoC peripherals, however likely it's desirable in any case where the PSRAM is touched.

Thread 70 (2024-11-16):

USB enumeration trouble

BrettRD, 2024-11-16:
I'm having trouble getting this to enumerate and I'm running out of things to check.

I've generated a platform description around the colorlight i5 on a breakout with a USB3300 phy (waveshare) with 12.2881MHz 'audio' domain.
The platform supports the luna `counter_device` example gateware and enumerates happily as a high-speed device

The soundcard gateware is recognised by the xhci-hcd driver as a high-speed device, but reliably fails to enumerate on my Debian 12 box.
```
[1403791.652666] usb 1-4: new high-speed USB device number 55 using xhci_hcd
[1403791.848705] usb 1-4: device descriptor read/64, error -71
... two retries ...
[1403792.860798] usb usb1-port4: attempt power cycle
[1403793.340669] usb 1-4: new high-speed USB device number 57 using xhci_hcd
[1403793.340798] usb 1-4: Device not responding to setup address.
[1403793.569218] usb 1-4: device descriptor read/8, error -71
... two more retries ...
[1403794.396822] usb usb1-port4: unable to enumerate USB device
```
This behaviour is consistent between the tiliqua repo's usb_audio gateware and the eurorack_pmod_usb_soundcard repo.

I had trouble isolating packets for this sequence in wireshark, I don't think it gets that far into enumeration; I can only spot the USBHUB events which weren't enlightening.

I'm starting to think I might have the wrong branch of your luna fork? I'm currently at e5eb71

I really like what you've done with the toolchains and conventions here, I'm looking forward to seeing what the Tiliqua becomes.

schnommus, 2024-11-16:
Hey @BrettRD,

> I'm starting to think I might have the wrong branch of your luna fork? I'm currently at e5eb71

For this repository that is not the correct hash, it is enforced by PDM to this commit: https://github.com/apfelaudio/tiliqua/blob/628c6176d3c617ae4f30475806a41a7887599792/gateware/pdm.lock#L556

For sanity's sake I just re-tested this example across all my machines (Tiliqua hardware, 3 separate computers, also using 12.288MHz audio domain):
- On Linux (kernel `6.11.7-arch1-1`): enumerates fine and able to record/playback in Audacity.
- On Mac (kernel `Darwin 23.4.0`): enumerates fine and able to record/playback in Audacity.
- On Windows (Win10 `10.0.19045`): enumerates fine and able to record/playback in Audacity.

In the above tests, I also tried disconnecting an re-connecting the USB device quite a few times and it always re-enumerated OK. So from my end the gateware itself seems solid  (at least in my default configuration).

If the above hash does not work for you, I would lean toward suspecting a signal integrity issue (especially if the waveshare adapter is connected through cables on a PMOD port), or something in the platform configuration leading to bus resets not being handled correctly.

If you haven't got one already, [cynthion](https://greatscottgadgets.com/cynthion/) is fantastic for debugging this kind of thing.

BrettRD, 2024-11-21:
Update: it was ULPI signal integrity.

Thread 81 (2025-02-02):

Tiliqua R3 outputs pegged at -10V indefinitely after cold boot (spurious, worse if DVI sink supplies 3.3V before powerup)

vk2seb, 2025-02-02:
It seems there may be an internal race condition causing the bootup sequence to sometimes fail to initialize the audio CODEC. Thus far I have not been able to reproduce myself.

From @matpalm:

> was stuck at 10V permanently. had an LFO into input0 and had output 2 and 3 going to mordax data. had it happen over two restarts ( power off / on ). then powered off, unplugged everything, powered back up and things were fine. HOWEVER, just now when i powered up, with everything still patched, it works for me :/ so i can't reproduce it...
could touch the inputs to "play the notes" which were being showed on the display, and could see the LED colours for outputs 2 and 3 in "shimmering yellow" in response to the touches, but the outputs were pegged to -10V

vk2seb, 2025-02-20:
I just accidentally experienced something today that looks VERY similar to this (everything started OK after boot except the audio CODEC, which stays pegged at -10V). The one thing I changed was that I was using a different display than usual (!!).

After some experimenting, I found that this issue reproduced (on this different display) under very specific scenarios:
- After a cold boot (waiting a while before turning on, with display cable connected), everything worked fine.
- Power cycling ~3sec after a HEALTHY boot with the display cable connected, this bug reproduced 100% of the time.
- Additionally, disconnecting the display cable from my laptop and immediately (under 2sec) reconnecting it to the tiliqua before powering up the eurorack system also reproduced this bug 100% of the time.
- With the display cable DISCONNECTED, I could not reproduce this bug at all.

After some probing, turns out this is a hardware artifact (!!) related to the soft-mute circuit. When a DVI sink (i.e a display) has its 3.3V terminations enabled (usually only a few seconds after an active display connection), it may back-power the Tiliqua through the 50R (sink) + 220R (tiliqua) series resistors into the ECP5. According to the ECP5 datasheet, this is permissible (even if the ECP5 is off). So it should not damage the hardware at least.

The consequence is we see ~1V on the 3.3V rail in this specific scenario, even if the Tiliqua is off. This means the soft-mute circuit never fully deasserts the PDN pin to the audio CODEC when the Tiliqua is powered off, which is required to initialize the CODEC correctly.

Fortunately, Tiliqua R3+ allow the FPGA to clock in the CODEC PDN value directly through a flip-flop. I just tried some experimental gateware to explicitly set a zero before the one on every boot. This made the bug disappear regardless of what I did with the display cable. So, fortunately, I don't think this will require another hardware rev.

I will leave this bug open until a mitigation is merged to `main` proper.

FYI @matpalm

vk2seb, 2025-03-04:
As of https://github.com/apfaudio/tiliqua/pull/88 detection/mitigation is added to the bootloader, which should make this bug disappear.

Closed 2025-03-04.

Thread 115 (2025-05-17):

Improve USB host autodetection

vk2seb, 2025-05-17:
Most Tiliqua examples shall support USB MIDI host for using MIDI keyboards to control it. However, the USB host support requires hard-coding some descriptor offsets which is not user-friendly. The correct host-settings should be detected automatically, allowing any USB-MIDI device to be used with Tiliqua without extra work.

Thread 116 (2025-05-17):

Add more `usb_audio` sample rate settings (e.g. 192kHz, 24bit)

vk2seb, 2025-05-17:
Currently `usb_audio` is fixed at 48kHz, 16bit, 4in + 4out. It should be possible to use 192kHz sampling or 24bit bit depth without too much extra work. Easier is a compiler flag, more complicated would be dynamic clock switching.

vk2seb, 2025-08-24:
This is now possible with the `--fs-192khz` flag and the `TILIQUA_ASQ_WIDTH` environment variable.

Closed 2025-08-24.

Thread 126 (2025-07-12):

Add save/load of all options from non-volatile flash on power loss

vk2seb, 2025-07-12:
Since all SoC bitstreams use a common options framework, it should also be possible to automatically serialize/deserialize the last settings used in every bitstream. This work could be split into a few different stages:

1) Write a filesystem driver that makes it easy to read/write keys from non volatile flash, compartmentalized to each bitstream slot. It must be a flash-friendly file system so we don't wear it down. Maybe this could be a good option: https://github.com/trussed-dev/littlefs2
2) Automatically serialize / deserialize all bitstream options whenever they are modified, and restore from the latest save whenever a bitstream is loaded
3) (optional) Automatically (from the bootloader bitstream) load the last user bitstream whenever power is cycled.

Overall, a power cycle of Tiliqua should result in us re-entering exactly the same state we were in before the power cycle.

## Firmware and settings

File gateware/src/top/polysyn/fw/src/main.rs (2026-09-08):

#![no_std]
#![no_main]

use critical_section::Mutex;
use log::{info, warn};
use riscv_rt::entry;
use irq::handler;
use core::cell::RefCell;

use micromath::F32Ext;
use midi_types::*;
use midi_convert::render_slice::MidiRenderSlice;
use midi_convert::parse::MidiTryParseSlice;

use tiliqua_pac as pac;
use tiliqua_hal as hal;
use tiliqua_lib::*;
use tiliqua_lib::draw;
use tiliqua_lib::dsp::OnePoleSmoother;
use tiliqua_lib::midi::MidiTouchController;
use pac::constants::*;
use tiliqua_hal::persist::Persist;
use tiliqua_fw::*;
use tiliqua_fw::options::*;
use opts::{Options, OptionTrait};
use opts::cc_map::{MidiCcMapper, CcMapMode};
use tiliqua_hal::pmod::EurorackPmod;

use tiliqua_hal::embedded_graphics::prelude::*;

use opts::persistence::*;
use hal::pca9635::Pca9635Driver;
use hal::tusb322::{TUSB322Driver, TUSB322Mode, AttachedState, AccessoryType};

use tiliqua_fw::wavetable;

pub const TIMER0_ISR_PERIOD_MS: u32 = 5;

fn adsr_ui_to_rate(ui_value: u16) -> u16 {
    // 0..32768 -> 1ms..2000ms -> hardware rate
    let ms_x32k = 32768u32 + ui_value as u32 * 1999;
    let rate = (45_000_000u64 / ms_x32k as u64) as u32;
    rate.min(65535) as u16
}

fn timer0_handler(app: &Mutex<RefCell<App>>) {

    critical_section::with(|cs| {

        let mut app = app.borrow_ref_mut(cs);

        //
        // Update UI and options
        //

        app.ui.update();
        let opts = app.ui.opts.clone();

        //
        // Check for TRS/USB MIDI traffic
        // (this is forwarded by the hardware to the synth
        //  for minimum possible latency, here we peek
        //  the FIFO contents for debugging purposes)
        //

        let mut last_cc_index = None;
        let midi_word = app.synth.midi_read();
        if midi_word != 0 {
            // Blink MIDI activity LED on TRS port
            app.ui.midi_activity();

            let bytes = [
                (midi_word & 0xFF) as u8,
                ((midi_word >> 8) & 0xFF) as u8,
                ((midi_word >> 16) & 0xFF) as u8,
            ];
            if let Ok(msg) = MidiMessage::try_parse_slice(&bytes) {
                if let MidiMessage::ControlChange(_, cc, val) = msg {
                    if let Some(action) = app.cc_mapper.process(cc.into(), val.into()) {
                        last_cc_index = Some(action.global_index);
                        apply_cc_action(&mut app.ui.opts, &action);
                    }
                }
            }

            // Optionally dump raw MIDI messages out serial port.
            if opts.misc.serial_debug.value == UsbMidiSerialDebug::On {
                info!("midi: 0x{:x} 0x{:x} 0x{:x}",
                      bytes[0], bytes[1], bytes[2]);
            }
        }

        // Highlight the last CC-modified option (once per cycle)
        if opts.misc.cc_highlight.value == CcHighlight::On {
            if let Some(idx) = last_cc_index {
                app.ui.opts.select_global(idx);
                app.ui.external_modify();
            }
        }

        //
        // Update synthesizer
        //

        let drive_smooth = app.drive_smoother.proc_u16(opts.effect.drive.value);
        app.synth.set_drive(drive_smooth);

        // Map 0-1 UI range to 32768-8192 hardware range (inverted)
        let reso_ui = opts.voice.reso.value as u32;
        let reso_hw = (32768 - reso_ui * 24576 / 32768) as u16;
        let reso_smooth = app.reso_smoother.proc_u16(reso_hw);
        app.synth.set_reso(reso_smooth);

        let diffuse_smooth = app.diffusion_smoother.proc_u16(opts.effect.diffuse.value);
        let coeff_dry: i32 = (32768 - diffuse_smooth) as i32;
        let coeff_wet: i32 = diffuse_smooth as i32;

        app.synth.set_matrix_coefficient(0, 0, coeff_dry);
        app.synth.set_matrix_coefficient(1, 1, coeff_dry);
        app.synth.set_matrix_coefficient(2, 2, coeff_dry);
        app.synth.set_matrix_coefficient(3, 3, coeff_dry);

        app.synth.set_matrix_coefficient(0, 4, coeff_wet);
        app.synth.set_matrix_coefficient(1, 5, coeff_wet);
        app.synth.set_matrix_coefficient(2, 6, coeff_wet);
        app.synth.set_matrix_coefficient(3, 7, coeff_wet);

        let mpe = opts.misc.mpe.value == Mpe::On;
        app.synth.set_mpe(mpe);
        app.synth.set_pitch_bend_range(opts.misc.pb_range.value.semitones());
        app.synth.set_midi_channel_filter(
            if mpe { None } else { opts.misc.midi_ch.value.to_filter() });

        // ADSR params
        app.synth.set_attack_rate(adsr_ui_to_rate(opts.adsr.attack.value));
        app.synth.set_decay_rate(adsr_ui_to_rate(opts.adsr.decay.value));
        app.synth.set_sustain_level((opts.adsr.sustain.value as u32 * 65535 / 32768) as u16);
        app.synth.set_release_rate(adsr_ui_to_rate(opts.adsr.release.value));

        // LFO -> phase modulation CSR
        {
            use wavetable::{Fix32, CYCLE_LEN};
            let isr_rate = Fix32::from_num(1000u32 / TIMER0_ISR_PERIOD_MS);
            // lfo_rate option: 0..50 -> 0..5.0 Hz
            // Q16.16 from_bits: value * 65536 / 10 = value * 6554
            let rate_hz = Fix32::from_bits(opts.voice.lfo_rate.value as i32 * 6554);
            let phase_inc = rate_hz * CYCLE_LEN as i32 / isr_rate;
            // depth option: 0..32768 -> 0..1.0
            let depth = Fix32::from_bits(opts.voice.lfo_depth.value as i32 * 2);
            let lfo_val = wavetable::wt_lfo(&mut app.lfo_phase, phase_inc, depth,
                                           Waveform::Sine);
            app.synth.set_lfo(lfo_val);
        }

        // Wavetable update on parameter change
        if opts.voice.waveform.value != app.last_waveform
            || opts.voice.proc.value != app.last_proc_mode
            || opts.voice.proc_amt.value != app.last_proc_amt
        {
            wavetable::wt_write(&mut app.synth, opts.voice.waveform.value,
                                opts.voice.proc.value, opts.voice.proc_amt.value);
            app.last_waveform = opts.voice.waveform.value;
            app.last_proc_mode = opts.voice.proc.value;
            app.last_proc_amt = opts.voice.proc_amt.value;
        }

        // Touch controller logic (sends MIDI to internal polysynth)
        if opts.misc.touch_ctrl.value == TouchControl::On {
            app.ui.touch_led_mask(0b00111111);
            let touch = app.ui.pmod.touch();
            let jack = app.ui.pmod.jack();

            // Output 1 (jack 5): auto mode when plugged (shows clock from DAC)
            if (jack & (1 << 5)) != 0 {
                app.ui.pmod.led_set_auto(5);
            }
            let msgs = app.touch_controller.update(&touch, jack);
            for msg in msgs {
                if msg != MidiMessage::Stop {
                    // TODO move MidiMessage rendering into HAL, perhaps
                    // even inside synth.midi_write.
                    let mut bytes = [0u8; 3];
                    msg.render_slice(&mut bytes);
                    let v: u32 = (bytes[2] as u32) << 16 |
                                 (bytes[1] as u32) << 8 |
                                 (bytes[0] as u32) << 0;
                    app.synth.midi_write(v);
                }
            }
        }
    });
}

fn global_index(opts: &Opts, opt: &dyn OptionTrait) -> usize {
    let key = opt.key().value();
    opts.all().enumerate()
        .find(|(_, o)| o.key().value() == key)
        .expect("cc_map: option key not found").0
}

fn apply_cc_action(opts: &mut Opts, action: &opts::cc_map::CcAction) {
    if let Some(opt) = opts.all_mut().nth(action.global_index) {
        match action.mode {
            CcMapMode::Absolute => { opt.set_from_cc(action.cc_value); }
        }
    }
}

fn build_cc_mapper(opts: &Opts) -> MidiCcMapper {
    let mut m = MidiCcMapper::new();
    // Voice page (CC 20-25)
    m.add(20, global_index(opts, &opts.voice.waveform),  CcMapMode::Absolute);
    m.add(21, global_index(opts, &opts.voice.proc),      CcMapMode::Absolute);
    m.add(22, global_index(opts, &opts.voice.proc_amt),  CcMapMode::Absolute);
    m.add(23, global_index(opts, &opts.voice.reso),      CcMapMode::Absolute);
    m.add(24, global_index(opts, &opts.voice.lfo_rate),  CcMapMode::Absolute);
    m.add(25, global_index(opts, &opts.voice.lfo_depth), CcMapMode::Absolute);
    // ADSR page (CC 30-33)
    m.add(30, global_index(opts, &opts.adsr.attack),  CcMapMode::Absolute);
    m.add(31, global_index(opts, &opts.adsr.decay),   CcMapMode::Absolute);
    m.add(32, global_index(opts, &opts.adsr.sustain), CcMapMode::Absolute);
    m.add(33, global_index(opts, &opts.adsr.release), CcMapMode::Absolute);
    // Effect page (CC 40-41)
    m.add(40, global_index(opts, &opts.effect.drive),    CcMapMode::Absolute);
    m.add(41, global_index(opts, &opts.effect.diffuse),  CcMapMode::Absolute);
    // Beam page (CC 50-55, CC 52 formerly decay now unused)
    m.add(50, global_index(opts, &opts.beam.scale),     CcMapMode::Absolute);
    m.add(51, global_index(opts, &opts.beam.persist),   CcMapMode::Absolute);
    m.add(53, global_index(opts, &opts.beam.intensity), CcMapMode::Absolute);
    m.add(54, global_index(opts, &opts.beam.hue),       CcMapMode::Absolute);
    m.add(55, global_index(opts, &opts.beam.palette),   CcMapMode::Absolute);
    m
}

struct App {
    ui: ui::UI<Encoder0, EurorackPmod0, I2c0, Opts>,
    synth: Polysynth0,
    drive_smoother: OnePoleSmoother,
    reso_smoother: OnePoleSmoother,
    diffusion_smoother: OnePoleSmoother,
    touch_controller: MidiTouchController,
    // wavetable state
    last_waveform: Waveform,
    last_proc_mode: ProcMode,
    last_proc_amt: u16,
    // midi cc mapper
    cc_mapper: MidiCcMapper,
    // lfo phase accumulator
    lfo_phase: wavetable::Fix32,
}

impl App {
    pub fn new(opts: Opts) -> Self {
        let peripherals = unsafe { pac::Peripherals::steal() };
        let encoder = Encoder0::new(peripherals.ENCODER0);
        let pmod = EurorackPmod0::new(peripherals.PMOD0_PERIPH);
        let i2cdev = I2c0::new(peripherals.I2C0);
        let pca9635 = Pca9635Driver::new(i2cdev);
        let drive_smoother = OnePoleSmoother::new(0.05f32);
        let reso_smoother = OnePoleSmoother::new(0.05f32);
        let diffusion_smoother = OnePoleSmoother::new(0.05f32);
        let touch_controller = MidiTouchController::new();
        let cc_mapper = build_cc_mapper(&opts);
        let mut synth = Polysynth0::new(peripherals.SYNTH_PERIPH);
        synth.usb_host_midi(1, 1);
        synth.usb_host_vbus(false); // default, but set anyway...
        Self {
            ui: ui::UI::new(opts, TIMER0_ISR_PERIOD_MS,
                            encoder, pca9635, pmod),
            synth,
            drive_smoother,
            reso_smoother,
            diffusion_smoother,
            touch_controller,
            last_waveform: Waveform::default(),
            last_proc_mode: ProcMode::default(),
            last_proc_amt: 0,
            cc_mapper,
            lfo_phase: wavetable::Fix32::ZERO,
        }
    }
}

#[entry]
fn main() -> ! {
    let peripherals = pac::Peripherals::take().unwrap();
    let sysclk = pac::clock::sysclk();
    let serial = Serial0::new(peripherals.UART0);
    let mut timer = Timer0::new(peripherals.TIMER0, sysclk);
    let mut persist = Persist0::new(peripherals.PERSIST_PERIPH);
    let spiflash = SPIFlash0::new(
        peripherals.SPIFLASH_CTRL,
        SPIFLASH_BASE,
        SPIFLASH_SZ_BYTES
    );
    crate::handlers::logger_init(serial);

    info!("Hello from Tiliqua POLYSYN!");

    let bootinfo = unsafe { bootinfo::BootInfo::from_addr(BOOTINFO_BASE) }.unwrap();
    let modeline = bootinfo.modeline.maybe_override_fixed(
        FIXED_MODELINE, CLOCK_DVI_HZ);
    let mut display = DMAFramebuffer0::new(
        peripherals.FRAMEBUFFER_PERIPH,
        peripherals.PALETTE_PERIPH,
        peripherals.BLIT,
        peripherals.PIXEL_PLOT,
        peripherals.LINE,
        PSRAM_FB_BASE,
        modeline.clone(),
        BLIT_MEM_BASE,
    );

    let mut i2cdev1 = I2c1::new(peripherals.I2C1);
    let mut pmod = EurorackPmod0::new(peripherals.PMOD0_PERIPH);
    calibration::CalibrationConstants::load_or_default(&mut i2cdev1, &mut pmod);

    use tiliqua_hal::cy8cmbr3xxx::Cy8cmbr3108Driver;
    let i2cdev_cy8 = I2c1::new(unsafe { pac::I2C1::steal() } );
    let mut cy8 = Cy8cmbr3108Driver::new(i2cdev_cy8, &TOUCH_SENSOR_ORDER);

    //
    // Create options and maybe load from persistent storage
    //

    let mut opts = Opts::default();
    let mut flash_persist_opt = if let Some(storage_window) = bootinfo.manifest.get_option_storage_window() {
        let mut flash_persist = FlashOptionsPersistence::new(spiflash, storage_window);
        flash_persist.load_options(&mut opts).unwrap();
        Some(flash_persist)
    } else {
        warn!("No option storage region: disable persistent storage");
        None
    };

    //
    // Configure TUSB322 (CC controller) in DFP/Host mode
    // This is needed if Tiliqua is connected to a device with a true USB-C to USB-C cable.
    // It is also used for detecting (and preventing) applying VBUS if we have a host/host
    // connection.
    //
    // TODO: disable terminations when host mode is disabled?
    // TODO: draw error text if this fails?
    //

    let i2cdev = I2c0::new(peripherals.I2C0);
    let mut tusb322 = TUSB322Driver::new(i2cdev);
    tusb322.soft_reset().ok();
    tusb322.disable_term().ok();

    //
    // Create App instance
    //

    let mut last_palette = opts.beam.palette.value.clone();
    let app = Mutex::new(RefCell::new(App::new(opts)));

    handler!(timer0 = || timer0_handler(&app));

    irq::scope(|s| {

        s.register(handlers::Interrupt::TIMER0, timer0);

        timer.enable_tick_isr(TIMER0_ISR_PERIOD_MS,
                              pac::Interrupt::TIMER0);

        let mut vscope = Vector0::new(peripherals.VECTOR_PERIPH);
        let mut first = true;

        let h_active = display.size().width;
        let v_active = display.size().height;

        let mut last_jack = pmod.jack();

        let mut last_attached_state = AttachedState::NotAttached;
        let mut last_opt_host_enabled = false;

        loop {

            let (opts, notes, cutoffs, draw_options, save_opts, wipe_opts) = critical_section::with(|cs| {
                let mut app = app.borrow_ref_mut(cs);
                if pmod.jack() != last_jack {
                    // Re-calibrate touch sensing on jack swaps.
                    let _ = cy8.reset();
                }
                last_jack = pmod.jack();
                let save_opts = app.ui.opts.misc.save_opts.poll();
                let wipe_opts = app.ui.opts.misc.wipe_opts.poll();

                // USB Host: Disable DFP terminations if `MISC->usb-host` option is off
                //
                // This stops us supplying VCONN on the CC pins for e-tagged cables, fixing an
                // edge case where we may backpower VBUS due to the following bug on
                // early Tiliqua R5.1s: https://github.com/apfaudio/tiliqua-hardware/issues/1
                //

                let opt_host_enabled = app.ui.opts.misc.usb_host.value == UsbHost::On;
                if last_opt_host_enabled != opt_host_enabled {
                    if opt_host_enabled {
                        tusb322.soft_reset().ok();
                        tusb322.set_mode(TUSB322Mode::Dfp).ok();
                    } else {
                        tusb322.disable_term().ok();
                        app.synth.usb_host_vbus(false);
                    }
                }
                last_opt_host_enabled = opt_host_enabled;

                // Type-C hotplugging detection
                //
                // Only enable VBUS if the TUSB322 Type-C controller says we are attached as:
                // - Attached.SRC
                // - Attached.ACCESSORY && AccessoryType.DebugDfp
                //
                // Due to the same hardware bug as above, Tiliqua's host port in DFP mode may
                // have the TUSB322I see some rare adapter combinations as `DebugDfp` accessories,
                // rather than `Attached.SRC`. To work around this, we still power VBUS on `DebugDfp`.
                //

                if let Ok(ctrl) = tusb322.read_connection_status_control() {
                    if let Ok(conn) = tusb322.read_connection_status() {
                        // Only update on valid reads to reduce risk of unintended toggling mid-stream
                        if ctrl.attached_state != last_attached_state {
                            info!("USB CC hotplug: {:?} | {:?}", ctrl, conn);
                            last_attached_state = ctrl.attached_state;
                        }
                        // Check how we are attached
                        let attached_src = ctrl.attached_state == AttachedState::AttachedSrc;
                        let attached_debug_dfp =
                            (ctrl.attached_state == AttachedState::AttachedAccessory) &&
                            (conn.accessory == AccessoryType::DebugDfp);
                        app.synth.usb_host_vbus(opt_host_enabled && (attached_src || attached_debug_dfp));
                    }
                }

                //
                // Copy out all the bits of state we need for drawing
                //

                (app.ui.opts.clone(),
                 app.synth.voice_notes().clone(),
                 app.synth.voice_cutoffs().clone(),
                 app.ui.draw(),
                 save_opts,
                 wipe_opts)
            });

            if save_opts {
                if let Some(ref mut flash_persist) = flash_persist_opt {
                    flash_persist.save_options(&opts).unwrap();
                }
            }

            if wipe_opts {
                critical_section::with(|cs| {
                    let mut app = app.borrow_ref_mut(cs);
                    app.ui.opts = Opts::default();
                    if let Some(ref mut flash_persist) = flash_persist_opt {
                        flash_persist.erase_all().unwrap();
                    }
                });
            }

            let on_help_page = opts.tracker.page.value == Page::Help;

            if opts.beam.palette.value != last_palette || first {
                opts.beam.palette.value.write_to_hardware(&mut display);
                last_palette = opts.beam.palette.value;
            }

            if draw_options || on_help_page {
                let (x, y) = if on_help_page {
                    (h_active/2-30, v_active-100)
                } else {
                    (h_active/2-30, 70)
                };
                draw::draw_options(&mut display, &opts, x, y,
                                   opts.beam.hue.value).ok();
                draw::draw_name(&mut display, h_active/2, v_active-50, opts.beam.hue.value,
                                &bootinfo.manifest.name, &bootinfo.manifest.tag, &modeline).ok();
                if opts.tracker.page.value == Page::Adsr {
                    use draw::AdsrPhase;
                    let highlight = opts.selected().and_then(|i| {
                        match opts.view().options()[i].key().value() {
                            v if v == opts.adsr.attack.key().value()  => Some(AdsrPhase::Attack),
                            v if v == opts.adsr.decay.key().value()   => Some(AdsrPhase::Decay),
                            v if v == opts.adsr.sustain.key().value() => Some(AdsrPhase::Sustain),
                            v if v == opts.adsr.release.key().value() => Some(AdsrPhase::Release),
                            _ => None,
                        }
                    });
                    draw::draw_adsr(&mut display,
                        h_active/2-190, 75,
                        125, 40,
                        opts.adsr.attack.value,
                        opts.adsr.decay.value,
                        opts.adsr.sustain.value,
                        opts.adsr.release.value,
                        opts.beam.hue.value,
                        highlight).ok();
                }
                if opts.tracker.page.value == Page::Voice {
                    const PREVIEW_LEN: usize = 64;
                    let mut preview = [0i16; PREVIEW_LEN];
                    wavetable::wt_preview(&mut preview,
                        opts.voice.waveform.value, opts.voice.proc.value,
                        opts.voice.proc_amt.value);
                    draw::draw_waveform_preview(&mut display,
                        h_active/2-190, 80,
                        125, 40,
                        opts.beam.hue.value,
                        &preview).ok();
                }
            }

            if on_help_page {
                draw::draw_help_page(&mut display,
                    MODULE_DOCSTRING,
                    bootinfo.manifest.help.as_ref(),
                    h_active,
                    v_active,
                    opts.help.scroll.value,
                    opts.beam.hue.value).ok();
                persist.set_persistence(64);
                vscope.set_enabled(false);
            } else {
                persist.set_persistence(opts.beam.persist.value);
                vscope.set_enabled(true);
            }

            vscope.set_hue(opts.beam.hue.value);
            vscope.set_intensity(opts.beam.intensity.value);
            vscope.set_xscale(opts.beam.scale.value);
            vscope.set_yscale(opts.beam.scale.value);
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

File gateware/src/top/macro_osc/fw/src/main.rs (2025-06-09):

// See top-level comment in 'top.py' for usage information.

#![no_std]
#![no_main]

use log::info;
use riscv_rt::entry;
use core::cell::RefCell;
use critical_section::Mutex;
use irq::handler;
use embedded_alloc::LlffHeap as Heap;
use mi_plaits_dsp::dsp::voice::{Modulations, Patch, Voice};
use embedded_graphics::prelude::*;

use tiliqua_pac as pac;
use tiliqua_hal as hal;
use tiliqua_fw::*;
use tiliqua_lib::*;
use pac::constants::*;
use tiliqua_hal::persist::Persist;
use options::*;
use hal::pca9635::*;
use hal::dma_framebuffer::Rotate;

pub const TIMER0_ISR_PERIOD_MS: u32 = 5;
const BLOCK_SIZE: usize = 128;
// PSRAM heap for big audio buffers.
const HEAP_START: usize = PSRAM_BASE + (PSRAM_SZ_BYTES / 2);
const HEAP_SIZE: usize = 128*1024;

static HEAP: Heap = Heap::empty();

struct App<'a> {
    voice: Voice<'a>,
    patch: Patch,
    modulations: Modulations,
    ui: ui::UI<Encoder0, EurorackPmod0, I2c0, Opts>,
}

impl<'a> App<'a> {
    pub fn new(opts: Opts) -> Self {
        let mut voice = Voice::new(&HEAP, BLOCK_SIZE);
        let mut patch = Patch::default();

        patch.engine = 0;
        patch.harmonics = 0.5;
        patch.timbre = 0.5;
        patch.morph = 0.5;
        patch.timbre_modulation_amount = 0.5;
        patch.morph_modulation_amount  = 0.5;
        voice.init();

        let peripherals = unsafe { pac::Peripherals::steal() };
        let encoder = Encoder0::new(peripherals.ENCODER0);
        let i2cdev = I2c0::new(peripherals.I2C0);
        let pca9635 = Pca9635Driver::new(i2cdev);
        let pmod = EurorackPmod0::new(peripherals.PMOD0_PERIPH);

        Self {
            voice,
            patch,
            modulations: Modulations::default(),
            ui: ui::UI::new(opts, TIMER0_ISR_PERIOD_MS,
                            encoder, pca9635, pmod),
        }
    }
}

// TODO: move this to hardware as it is quite expensive.
#[inline(always)]
pub fn f32_to_i32(f: u32) -> i32 {
    let a = f & !0 >> 1; // Remove sign bit.
    if a < 127 << 23 { // >= 0, < 1
        0
    } else if a < 158 << 23 { // >= 1, < max
        let m = 1 << 31 | a << 8; // Mantissa and the implicit 1-bit.
        let s = 158 - (a >> 23); // Shift based on the exponent and bias.
        let u = (m >> s) as i32; // Unsigned result.
        if (f as i32) < 0 { -u } else { u }
    } else  { // >= max (incl. inf)
        if (f as i32) < 0 { i32::MIN } else { i32::MAX }
    }
}

fn timer0_handler(app: &Mutex<RefCell<App>>) {

    let peripherals = unsafe { pac::Peripherals::steal() };
    let audio_fifo = peripherals.AUDIO_FIFO;
    let pmod = peripherals.PMOD0_PERIPH;

    critical_section::with(|cs| {

        let mut app = app.borrow_ref_mut(cs);

        //
        // Update UI and options
        //

        app.ui.update();

        //
        // Patch settings from UI
        //

        let opts = app.ui.opts.clone();
        let mut patch = app.patch.clone();

        patch.engine    = opts.osc.engine.value as usize;
        patch.note      = opts.osc.note.value as f32;
        patch.harmonics = (opts.osc.harmonics.value as f32) / 256.0f32;
        patch.timbre    = (opts.osc.timbre.value as f32) / 256.0f32;
        patch.morph     = (opts.osc.morph.value as f32) / 256.0f32;

        //
        // Modulation sources from jacks
        //

        let mut modulations = app.modulations.clone();
        let jack = pmod.jack().read().bits();

        let note_patched = (jack & 0x1) != 0;
        modulations.trigger_patched   = (jack & 0x2) != 0;
        modulations.timbre_patched    = (jack & 0x4) != 0;
        modulations.morph_patched     = (jack & 0x8) != 0;

        if note_patched {
            // 1V/oct
            let v_oct = ((pmod.sample_i0().read().bits() as i16) as f32) / 4000.0f32;
            modulations.note = v_oct * 12.0f32;
        }

        modulations.trigger = ((pmod.sample_i1().read().bits() as i16) as f32) / 16384.0f32;
        modulations.timbre = ((pmod.sample_i2().read().bits() as i16) as f32) / 16384.0f32;
        modulations.morph = ((pmod.sample_i3().read().bits() as i16) as f32) / 16384.0f32;

        //
        // Render audio
        //

        let mut out = [0.0f32; BLOCK_SIZE];
        let mut aux = [0.0f32; BLOCK_SIZE];

        let mut n_attempts = 0;
        while (audio_fifo.fifo_len().read().bits() as usize) < AUDIO_FIFO_ELASTIC_SZ - BLOCK_SIZE {
            n_attempts += 1;
            if n_attempts > 10 {
                // TODO set underrun flag
                break
            }
            app.voice
               .render(&patch, &modulations, &mut out, &mut aux);
            for i in 0..BLOCK_SIZE {
                unsafe {
                    let fifo_base = AUDIO_FIFO_MEM_BASE as *mut u32;
                    *fifo_base = f32_to_i32((out[i]*16000.0f32).to_bits()) as u32;
                    *fifo_base.add(1) = f32_to_i32((aux[i]*16000.0f32).to_bits()) as u32;
                }
            }
        }

    });
}
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

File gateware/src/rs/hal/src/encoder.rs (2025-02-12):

pub trait Encoder {
    fn poke_ticks(&mut self) -> i8;
    fn poke_btn(&mut self) -> bool;
    fn update(&mut self);
}

#[macro_export]
macro_rules! impl_encoder {
    ($(
        $ENCODERX:ident: $PACENCODERX:ty,
    )+) => {
        $(
            #[derive(Debug)]
            pub struct $ENCODERX {
                registers: $PACENCODERX,

                rot: i16,
                lrot: i16,
                lbtn: bool,

                pending_ticks: i8,
                pending_release: bool,
                pending_press:   bool,
            }

            impl $ENCODERX {
                pub fn new(registers: $PACENCODERX) -> Self {
                    let btn = registers.button().read().bits() != 0;
                    Self { registers,
                           rot: 0,
                           lrot: 0,
                           lbtn: btn,
                           pending_ticks: 0,
                           pending_release: false,
                           pending_press: false
                    }
                }

            }

            impl hal::encoder::Encoder for $ENCODERX {
                /// Check for pending ticks and clear them.
                fn poke_ticks(&mut self) -> i8 {
                    let ticks = self.pending_ticks;
                    self.pending_ticks = 0;
                    ticks
                }

                /// Check for pending clicks and erase it.
                fn poke_btn(&mut self) -> bool {
                    let btn = self.pending_press && self.pending_release;
                    if btn {
                        self.pending_press = false;
                        self.pending_release = false;
                    }
                    btn
                }

                fn update(&mut self) {

                    self.rot += (self.registers.step().read().bits() as i8) as i16;
                    let btn = self.registers.button().read().bits() != 0;
                    let mut delta_ticks = self.rot - self.lrot;

                    // This logic is dumb. Move it into RTL.

                    while delta_ticks > 1 {
                        self.pending_ticks += 1;
                        delta_ticks -= 2;
                    }

                    while delta_ticks < -1 {
                        self.pending_ticks -= 1;
                        delta_ticks += 2;
                    }

                    // button just released
                    if self.lbtn != btn {
                        if btn {
                            self.pending_press = true;
                        } else {
                            self.pending_release = true;
                        }
                    }

                    self.lrot = self.rot - delta_ticks;
                    self.lbtn = btn;
                }
            }

            impl From<$PACENCODERX> for $ENCODERX {
                fn from(registers: $PACENCODERX) -> $ENCODERX {
                    $ENCODERX::new(registers)
                }
            }
        )+
    }
}

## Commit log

2025-02-05 tiliqua/audio: rewrite I2S and calibration module, improve testbenches (#82)
    - Completely remove dependency on `eurorack_pmod` verilog modules that were still used for some low-level I2S and calibration functions, rewriting them in Amaranth. Delete this submodule.
    - Improve a few things on the way:
    - Update and re-test all example bitstreams to adhere to the above.
    - `usb_audio` bitstream now uses native streams for mating to the audio interface, should be easier to hook this up to other things.
    - Remove `AudioStream` module, domain crossing FIFOs now become part of `EurorackPmod`.
    - Add a simple SVG plotting library to DSP verilator testbenches.
    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
2025-02-07 tiliqua/audio: add SoC registers for writing calibration constants
2025-02-08 top/selftest: improved calibration UI
2025-02-08 top/selftest: print calibration equations
2025-02-08 top/selftest: serial print cal constants
2025-02-08 top/selftest: quench some errors
    [main.rs]
2025-02-09 docs/calibration: document calibration process
2025-02-09 tiliqua_soc: add i2c override to eurorack-pmod bus
2025-02-09 tiliqua_soc/i2c1: test op, doesn't work due to incorrect i2c1 semantics
    [eurorack_pmod.py, i2c.py, lib.rs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]
2025-02-10 i2c/audio: fix error handling on i2c override
    [i2c.py]
2025-02-10 selftest/cal: cleanup, print after cal write
2025-02-11 lib/ui: fix green page select led lag
2025-02-11 hal: add some encoder/pca traits
2025-02-11 top/all: add calibration reads to all SoC bitstreams
2025-02-12 docs/cal: update calibration documentation
2025-02-12 Revert "rs/ui: remove macro usage from ui::UI"
    This reverts commit 6d869ea344a387c2594569cc0f60d3fea39cd47f.
    [main.rs]
2025-02-12 test/i2c: update i2c unit tests
2025-02-18 rs/opts: reduce option library footprint (#85)
    - Move `opts` out of `rs/lib` and into new independent crates `opts`/`opts-derive`.
    - Refactor all `opts` macros into derive-like proc macros, to reduce duplication.
    - Reduce all `opts` datatype sizes by moving step/min/max/name into shared constant storage.
    - Measured: memory footprint of ~50 options reduced from ~3KiB to ~0.8KiB
    - Stepping stone required for option serialization/deserialization across power loss
    - Add and test `FloatOption` type (currently not used anywhere) and incomplete `StringOption` (only used in bootloader for rendering)
2025-02-22 top/bootloader: add 0.5sec startup LED animation (#86)
    * top/bootloader: add bootloader startup animation to LEDs
    * top/bootloader: move startup animation into impl App
2025-02-23 manifest: handle optional keys correctly, add magic / hw_rev to manifest WARN: invalidates all previous manifests!
    [cli.py, flash.py, types.py]
2025-02-24 bootloader: streamline error checking
    [main.rs, tiliqua_soc.py]
2025-03-04 bootloader: detect/mitigate DVI leakage current halting CODEC init (issue: #81) (PR: #88)
    Bug details from https://github.com/apfaudio/tiliqua/issues/81:
    ```
    After some probing, turns out this is a hardware artifact (!!) related to the soft-mute circuit. When a DVI sink (i.e a display) has its 3.3V terminations enabled (usually only a few seconds after an active display connection), it may back-power the Tiliqua through the 50R (sink) + 220R (tiliqua) series resistors into the ECP5. According to the ECP5 datasheet, this is permissible (even if the ECP5 is off). So it should not damage the hardware at least.
    The consequence is we see ~1V on the 3.3V rail in this specific scenario, even if t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
    [eurorack_pmod.py, eurorack_pmod_peripheral.py, main.rs]
2025-03-09 dma_framebuffer/dvi/tmds: rewrite video backend, general cleanup (#89)
    - Rewrite DVI PHY and TMDS encoder in Amaranth (this was the last verilog carryover)
    - Added test cases for DC bias and control mode switching
    - Compartmentalize all the components of the `DMAFramebuffer` to aid readability:
    - Move `DVITimingGen`, `DVIPHY` into their own `dvi.py` as they may be useful elsewhere.
    - Move `Palette` out of `DMAFramebuffer` and into its own component to aid readability.
    - Rename `DVITimings` to `DVIModeline` to better represent the fact that this class just holds some constants describing video timings.
    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
2025-03-10 dvi/tmds/dsp: additional pipeline stages to improve fmax (#90)
    * dvi/tmds: additional pipeline stage to close timing
    * dsp/polysyn: pipeline some DSP components to improve Fmax [polysyn tested]
    * dma_framebuffer: bump fifo 512 -> 1024 words for stability
    [dma_framebuffer.py, dsp.py, dvi.py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]
2025-03-12 bootloader/flasher: pop-free bitstream flashing from bootloader (#91)
    A few changes so that `pdm flash archive` and `pdm flash status` don't cause audio pops when run from the `bootloader` bitstream.
    - Always mute audio codec from `bootloader bitstream`
    - Always issue `openFPGALoader` commands with `--skip-reset` on all but the last command
    - Rewrite `flash.py` so it's a bit more maintainable
    - Add some ASCII art showing the SoldierCrab flash layout.
    [flash.py, main.rs]
2025-03-12 dvi: fix typo in hsync inversion flag
    [dvi.py]
2025-03-14 top/bootloader: startup diagnostics / nvm programming of cy8cmbr3xxx (#92)
    - Add cy8cmbr3xxx NVM programming from bootloader if the config doesn't match what we expect.
    - Report any startup or CRC mismatch warnings in the bootloader screen and advice to avoid them.
    [cy8cmbr3xxx.rs, lib.rs, main.rs]
2025-03-20 top/cli: add support for parallel builds (#96)
    Add support for parallel builds, under the following conditions:
    - Parallel builds are for projects with different names or hardware revisions
    - Parallel builds do not share the same Rust firmware binary target
    - As of now, no SoC bitstreams share binary targets, so this is fine.
    For an example, see `scripts`.
    Closes https://github.com/apfaudio/tiliqua/issues/95
    [cli.py, lib.rs, main.rs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]
2025-03-20 usb_host: handle ZLP nak in setup stage
2025-03-20 midi: various fixes for pss-a50 support
    - Treat zero-velocity note ON as note OFF
    - PSS-A50 emits note ON when a key is released,
    with zero velocity. Surprisingly, this is
    still standard compliant!
    - Ignore all SysEx messages for now
    - PSS-A50 sends a bunch of clock synchronization
    signals that we don't know how to handle yet.
    - Ignore mod wheel requests that are zero
    - PSS-A50 likes to send a zero mod-wheel message
    when pressing some buttons, which silences the
    Tiliqua. Ignore these.
    I tried my Keylab 49 and Yamaha CP73 and they still work fine
    with these changes.
    [midi.py]
2025-04-06 leds: dim all LEDs to 25% (#100)
    * Dimming them reduces current consumption and improves v/oct tracking a bit.
2025-04-21 future/fixed: update fixed-point implementation to match latest `lib.fixed` RFC (#103)
    - Modify Tiliqua codebase to use my latest implementation of the `lib.fixed` RFC.
    - Goal is to experiment with the ergonomics of `lib.fixed` and make sure it interacts with the rest of Amaranth and my existing DSP components without unexpected surprises.
    - `lib.fixed` is added out-of-tree under `amaranth_future.fixed`, so we can still point to upstream Amaranth releases.
    - This includes a large test suite of `lib.fixed` that is now run against `amaranth_future.fixed`.
    - Improvements along the way:
    - Remove all the signed/unsigned hacks that polluted `tiliqua.dsp`, now fixed by `lib.fixed`.
    - Remove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
    [delay.py, dsp.py, eurorack_pmod.py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]
2025-04-22 tiliqua_soc: reduce i2c0 bus speed to 100kHz for more reliable EDID reads
2025-04-24 selftest/macro_osc: print psram bandwidth stats
2025-04-25 tiliqua_soc: selftest runs on hardware sans timer isrs
2025-04-25 tiliqua_soc: fix timer isrs with new API
2025-04-25 tiliqua_soc: switch back to vendored vexriscv implementation for now
2025-04-25 delay_line/usb_host: fix build errors
    [delay_line.py, usb_host.py]
2025-04-25 luna-soc: switch to fork in deps/luna-soc submodule
2025-04-25 all: fix bug in top-level psram wishbone semantics (was fine on Vex, breaks Vexii)
    [cache.py, main.rs, psram_peripheral.py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]
2025-04-26 tiliqua_soc: swap vexriscv for vexiiriscv - TODO: propagate reset_addr correctly to core (only psram XiP supported, fixed 0x20000000 for now) - TODO: reduce resource usage, store flags in vexiiriscv.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
    [main.rs, sim.py, tiliqua_soc.py]
2025-04-27 vexii: fix bootloader startup, add special rv32im_xip CPU variant for direct spiflash XiP instruction fetches
    [tiliqua_soc.py]
2025-04-27 deps/luna-soc: switch dev submodule to pdm git dependency
2025-04-27 cache: remove dpram-backed cache option, it was buggy anyway and usually has a bad aspect ratio
    [cache.py]
2025-04-27 fixed broken link pico-dirty
2025-05-11 top/bootloader: fix persist, cleaner video mode report
    [main.rs]
2025-05-11 top/bootloader: cleanup, dynamic hotplug, mostly broken though
    [main.rs]
2025-05-11 macro_osc: update to take bootinfo modeline (FIXME: 90deg rotation of traces)
    [main.rs, scope.py]
2025-05-11 cli: fixed/dynamic modelines but it's pretty ugly :(
    [cli.py, dma_framebuffer.py, tiliqua_pll.py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]
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2025-05-11 cli/platform: fix static modes for SoC bitstreams
    [cli.py, dma_framebuffer.py, dvi_modeline.py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]
2025-05-11 all: fix modeline prints, propagate max pixel clock to bootloader TODO propagate pixel/audio clocks to lpf generation
    [main.rs]
2025-05-13 bootloader: fix bootinfo clk1 inherit prints
    [lib.rs, main.rs]
2025-05-14 all: fix dvi/dvi5x reset glitches
    [main.rs, tiliqua_soc.py]
2025-05-14 all: factor out fixed modeline logic
    [main.rs]
2025-05-14 all: forgot to stage small dma_fb change from dvi5x reset glitches?
    [dma_framebuffer.py]
2025-05-15 raster_persist: fix bug across timing changes
    [raster_persist.py]
2025-05-15 bootloader: dynamic hotplug mostly works TODO: EDID delay/retry TODO: Enter reset on HPD low?
    [main.rs]
2025-05-16 tiliqua_pll: fix bitstreams without video clock
    [tiliqua_pll.py]
2025-05-17 cli: set 1280x720p60 fixed modeline by default on r2/r3
    [cli.py, tiliqua_pll.py]
2025-05-17 tiliqua_platform: fix hpd pin for R2 mobo
    [tiliqua_platform.py]
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2025-05-17 xbeam: squash trigger jitter introduced by PSRAM bursts
    [scope.py]
2025-05-17 soc/sim: improve error message on attempting to simulate with dynamic modeline
    [sim.py]
2025-05-17 sid/scope: fix sid scope streams, clean up inputs
    [scope.py]
2025-05-24 usb_audio: improve feedback stability
    [eurorack_pmod.py, tiliqua_platform.py]
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2025-06-02 usb_audio: remove --flash option, resurrect ila, add overrun/underrun ADC/DAC logic
2025-06-04 usb_audio: temporarily revert over/underrun adc/dac logic
2025-06-04 xbeam: fix channel polarity, add plot fifo to quadscope for stability
    [raster_stroke.py]
2025-06-04 Revert "usb_audio: temporarily revert over/underrun adc/dac logic"
    This reverts commit e432b4558802755434a05d564bf5b860a2b5ec27.
2025-06-04 Reapply "usb_audio: temporarily revert over/underrun adc/dac logic"
    This reverts commit a1543c90aeffa2560dd13c16993ed77fd02495e1.
2025-06-06 dsp/xbeam: swap intensity/color polyphase resampling for cheaper duplicator
    [dsp.py, raster_stroke.py]
2025-06-07 macro_osc: fix build TODO: move plot_fifo out of stroke!
    [main.rs, scope.py]
2025-06-07 macro_osc: fix build, TODO disappearing vscope, occasional modal glitches
    [main.rs, raster_stroke.py]
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2025-06-08 platform/i2s: update r2/r3 hardware for ffbuffer i2s, fix i2s simulation
    [tiliqua_platform.py]
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2025-06-21 tiliqua_platform: r4: fix pinout error on ex0 pmod
    [tiliqua_platform.py]
2025-06-21 eurorack_pmod: add support for audio board connected through expansion pmods
2025-06-21 top/dsp: add TripleMirror example of using external audio boards
2025-06-25 selftest: reset touch IC on jack insert/remove
    [cy8cmbr3xxx.rs, main.rs]
2025-06-25 cy8: don't enable nonexistent sensors - saves ~40mA!
2025-06-25 cy8: fix uniform sensitivity
    [cy8cmbr3xxx.rs]
2025-06-25 polysyn: auto cy8 resets, fix unmute
    [main.rs]
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2025-06-25 platform: revert non-pseudo changes
    [tiliqua_platform.py]
2025-06-25 Revert "HACK: 24bit xbeam for audio testing"
    This reverts commit 3d75fa3388de924b3ecf18574fd32619e6973161.
    [eurorack_pmod.py, main.rs]
2025-06-25 platform/r5: fix ex0 pinouts, set pmod R3.4 scale factors
    [eurorack_pmod.py, tiliqua_platform.py]
2025-06-25 selftest/top: write something to fake rp2040 i2c eeprom 0x17
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2026-05-30 top/polysyn/tusb322i: enable VBUS when enumerating as Accessory/DebugDfp (#171)
    Fix for https://github.com/apfaudio/tiliqua/issues/170 - some USB C devices enumerate as DebugDfp and weren't supplied with VBUS.
    From the code --
    It seems some USB-C adapters will enumerate as a DebugDfp accessory. Enabling VBUS
    is still safe in this situation, as we can only land in DebugDfp if the CC
    controller is sure we are a DFP. It's not sufficient to just check
    Attached.ACCESSORY as we could also enumerate as an UFP accessory against a host!
    As for WHY some devices are enumerating as a DebugDfp, it would be good to have an answer. I need to break out the CY4500 at some point and trace one these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
    [main.rs]
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2026-06-07 top/polysyn/tusb322i: disable DFP terminations if usb-host option is off (#175)
    This stops us supplying VCONN on the CC pins for e-tagged cables when `usb-host` is OFF,
    fixing an edge case which may backpower VBUS due to the following bug on
    early Tiliqua R5.1s: https://github.com/apfaudio/tiliqua-hardware/issues/1
    I don't see this actually causing any issues as the TUSB322I has its own
    output current limiting for VCONN, so the worst we could do is supply a VBUS
    a bit lower than the device expects before VBUS proper arrives, but this should
    be fixed regardless.
    [main.rs]
2026-06-07 top/polysyn: add hardware MIDI channel filter on TRS/USB (#174)
    Add midi-ch option to MISC page, which can be `all` (default) to listen to all MIDI channels or `ch1, ch2 ...` for listening to a single MIDI channel.
2026-09-12 top/bootloader: clamp max spread-spectrum to 0.25%
    Values higher than this seem to cause rare video lock failures on
    a small population of devices. Verified in a TEM cell that the
    corresponding change to EMI/emissions is negligible (increase
    by ~5dB at some frequencies, but we had >15dB of margin from
    the last far-field measurements).
    [main.rs]
2026-09-12 top/bootloader: add short delay between framebuffer init and first palette write
    On MS2131-based devices (common ultra-cheap capture cards), this seems
    to help the devices lock to the video signal after a warm boot. Before
    this change, I see failure rates in the 20/100 range on warm boots.
    After it, I see 0/100 lock failures on warm boot. Cold boot and lock
    after reconfiguration were always successful 100% of the time in my
    testing.
    [main.rs]
2026-09-23 top/bootloader/fw: add i2c-driven reconfig for apfbug
    New versions of apfbug will not use UART-driven bitstream
    reconfiguration requests and instead use i2c-driven ones,
    as this allows us to simplify the usb-serial logic a lot.
    This is intentionally backwards-compatible with old versions
    of apfbug as we still print the BITSTREAMX message. So
    Tiliquas with an old RP2040 firmware will still accept this
    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
2026-10-25 top/fw: move polysynth/grain/delay_line drivers out of hal
    These are only used by 1 toplevel so let's not DRY to extremely
2026-10-25 top/sampler/fw: log delay line flash errors instead of panicking
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2026-10-25 rs/hal: swap summon with a TimerIrq with reduced powers
2026-10-25 top/*/fw: build UI in main, pass into App instead of stealing its drivers
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2026-10-25 rs/hal: drop unused summon() from serial, i2c and encoder
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2026-10-25 top/bootloader/fw: only switch display mode if PLL reconfigured ok
2026-10-25 top/*/fw: rename i2c devices to match what they talk with
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2026-10-31 tiliqua_soc, rs: remove all TIMER0 and legacy csr cruft
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
